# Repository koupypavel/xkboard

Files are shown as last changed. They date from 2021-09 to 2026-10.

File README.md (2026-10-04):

# XKboard

XKboard is a modular embedded development and teaching platform made of two independent PCBs:

| Board | Main device | On-board debug/programming | Docs |
|---|---|---|---|
| **XKboard MCU** | NXP LPC4327 (ARM Cortex-M4F + Cortex-M0 co-processor) | LPC11U35 CMSIS-DAP probe (see [known issues](#known-issues)), 10-pin JTAG/SWD header | [xkboard_mcu/README.md](xkboard_mcu/README.md) |
| **XKboard FPGA** | Lattice MachXO3D LCMXO3D-9400HC-5SG72C | FTDI FT2232HL USB-JTAG bridge, 10-pin JTAG header | [xkboard_fpga/README.md](xkboard_fpga/README.md) |

Each board works standalone and can be programmed and debugged on its own. Both boards expose
**Arduino-compatible headers** (3.3 V logic only), so standard Arduino shields can be attached.
The boards can also be stacked through the dedicated **`FPGA_CONF`** header, which carries
I2C and SPI between the two. With the boards stacked, the MCU can configure the FPGA (program
its internal flash through the MachXO3D sysCONFIG interface) and exchange data with the logic
running in it.

The project is inspired by the FITkit / Minerva boards used for teaching at FIT BUT. Unlike Minerva,
it splits the MCU and the FPGA onto separate, simpler boards. It was developed as the author's
master's thesis (see [Background](#background)).

## Repository layout

```
.
├── doc.pdf                    Master's thesis (Czech) – full technical report
├── docs/
│   ├── examples.md            Demonstration examples (MCU + FPGA + interconnect)
│   └── hardware-design.md     PCB design, manufacturing, assembly and bring-up notes
├── xkboard_mcu/               MCU board
│   ├── case/                  3D-printable enclosure (top.stl, bottom.stl)
│   ├── dps/                   Altium Designer project (schematics, PCB, libraries, outputs zip)
│   ├── firmware/              MCUXpresso examples, board library, OpenOCD/FT_PROG/FlashMagic configs
│   └── schema.pdf             Schematics
└── xkboard_fpga/              FPGA board
    ├── case/                  3D-printable enclosure (top.stl, bottom.stl)
    ├── dps/                   Altium Designer project (schematics, PCB, outputs zip)
    ├── firmware/              Lattice Diamond VHDL examples, FT_PROG template
    └── schema.pdf             Schematics
```

`dps` is the Czech abbreviation for PCB (*deska plošných spojů*).

## Getting started

1. **Pick a board.** Read the hardware overview and pinout in
   [xkboard_mcu/README.md](xkboard_mcu/README.md) or [xkboard_fpga/README.md](xkboard_fpga/README.md).
2. **Install the toolchain.**
   - MCU: [MCUXpresso IDE](https://www.nxp.com/mcuxpresso/ide) (GNU Arm Embedded toolchain included) and
     [OpenOCD](https://openocd.org/).
   - FPGA: [Lattice Diamond](https://www.latticesemi.com/latticediamond) (includes LSE, ModelSim Lattice
     Edition and the Reveal logic analyzer) and FTDI [FT_PROG](https://ftdichip.com/utilities/).
3. **Run the blink example** for your board. See [docs/examples.md](docs/examples.md#1-led-and-button-blink).
4. **Connect the boards.** Use the `FPGA_CONF` header for the I2C configuration and servo-control
   examples.

## Board interconnect

The `FPGA_CONF` header is in the same place on both boards. The FPGA board has pin headers on its
bottom side that plug into the female header on the MCU board.

| Signal | Function |
|---|---|
| `SCL`, `SDA` | I2C. Used for FPGA configuration (MachXO3D configuration port at 7-bit address `0x40`) and for user communication through the EFB I2C controllers |
| `CCLK`, `MOSI`, `MISO`, `SN` | SPI. Can be used for slave-SPI configuration of the FPGA or for user communication |
| `DONE`, `INITN` | FPGA configuration status pins |
| `GND` | Common ground |

> **Note:** On the MCU side the `FPGA_CONF` pins are not pre-assigned to these functions after reset. The
> firmware must configure the pin multiplexing (SCU) before any transfer.

Any free GPIOs (`MCU_IO` / `FPGA_IO` headers, Arduino headers) can also be used for custom protocols. The
servo-control example uses a simple 3-wire clock/data/strobe protocol.

## Known issues

- **MCU on-board debug probe:** the LPC11U35 CMSIS-DAP probe (DAPLink/SWDAP-based) is not usable in this
  revision. The JTAG TDI/TDO lines are not routed, and the LPC4327 comes up in JTAG mode by default.
  Use an external FT2232H-based JTAG adapter on the `SWD/JTAG` header instead (see
  [xkboard_mcu/README.md](xkboard_mcu/README.md#debugging)). A future revision should replace the probe,
  for example with an NXP MCU-Link-style design with full JTAG support.
- **MCU boot-mode pins** and the **FPGA reset circuit** needed rework during bring-up. See
  [docs/hardware-design.md](docs/hardware-design.md#bring-up-notes).
- The external SPI flash on the FPGA board is populated, but it is not used as a configuration source.
- Programming the FPGA internal flash over I2C from the MCU is only partially implemented. Erase, status
  and ID readout work, but there is no storage interface large enough to hold a bitstream.

## Background

This work was the basis of the master's thesis *Modular teaching platform for embedded systems and digital
circuits* (*Modulární výuková platforma pro oblast vestavěných systémů a číslicových obvodů*),
Pavel Koupý, Brno University of Technology, Faculty of Information Technology, 2021. The full report (in Czech)
is [doc.pdf](doc.pdf). The READMEs in this repository are an English technical adaptation of its practical parts.

**Keywords:** development board, ARM Cortex-M, FPGA, Arduino compatible, CMSIS-DAP on-board debug interface.

## License

See [LICENSE](LICENSE).

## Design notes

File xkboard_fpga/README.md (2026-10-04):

# XKboard FPGA

FPGA development board based on the Lattice **MachXO3D** family. It has an on-board USB-JTAG bridge, an
Arduino-compatible header, and a header for stacking with the [XKboard MCU](../xkboard_mcu/README.md) board.

- Schematics: [schema.pdf](schema.pdf)
- Altium Designer project: [dps/](dps/) (`fitkit4_fpga.PrjPcb`; fabrication outputs in `xkboard_fpga.zip`)
- Enclosure: [case/](case/) (`top.stl`, `bottom.stl`)
- VHDL examples and FT_PROG template: [firmware/](firmware/README.md)

The board design draws on FITkit 3 (Minerva), Spartan Edge Accelerator and Arty S7. Lattice was chosen over
Xilinx because the MachXO3D can be configured over open interfaces (I2C, SPI, JTAG) without a vendor-specific
programming cable.

## Hardware

### FPGA

| Parameter | Value |
|---|---|
| Device | Lattice LCMXO3D-9400HC-5SG72C |
| Logic | 9400 LUT4s, EBR block RAM, distributed RAM |
| Package | QFN72 with exposed pad, 58 user I/O |
| Supply | 2.5–3.3 V (core and I/O banks; 3.3 V on this board) |
| Non-volatile memory | Internal configuration flash (CFG0/CFG1) and user flash (UFM) |
| Hard IP | EFB: 2× I2C, SPI, timer/counter, UFM access, sysCONFIG via Wishbone. ESB: AES-128/256, SHA-256/HMAC, ECC, TRNG. sysCLOCK PLL |
| Clock | 12 MHz oscillator on pin 69 |

#### Architecture notes (MachXO3D)

- **PFU** (Programmable Functional Unit): 4 slices, each with 2 LUT4s and 2 registers. Slice modes are Logic (LUT4/LUT5),
  Ripple (2-bit add/sub, counters, comparators, multipliers with fast carry FCI/FCO), RAM (16×4 distributed
  single-port RAM) and ROM.
- **sysIO** buffers support LVTTL, LVCMOS33/25/18/15/12, I3C, LVDS and MIPI, depending on the bank VCCIO.
- **Clocking:** 8 primary clock inputs (`PCLK[T/C][bank]_[0..2]`). They can be used as general I/O when not
  needed as clock inputs.
- **EFB / ESB** blocks are accessed from user logic over a **Wishbone** bus. User logic must implement a
  Wishbone master: either a custom state machine, or a soft-core such as Mico8/Mico32. Lattice does not officially support
  those cores on MachXO3D (Mico8 supports MachXO3L).

**Internal flash map:** `CFG0` and `CFG1` hold the primary and secondary bitstreams. They are followed by
the user flash sectors `UFM0`–`UFM3`. A bitstream larger than a CFG sector may extend into the UFM sector
directly after it. The **Feature Row** is erased and programmed separately. It enables or disables the
configuration ports (I2C, SPI, JTAG) and the dedicated pins `PROGRAMN`, `INITN` and `DONE`.

**Configuration ports:** IEEE 1149.1 JTAG, self-download (from internal flash), master/slave SPI, dual boot,
I2C and Wishbone. All use the **sysCONFIG** command set. The device switches between **User**, **Offline**
and **Transparent** configuration modes. Offline mode must be entered before reprogramming, so that the
running logic is disabled while the flash or SRAM is rewritten.

### Debug and configuration

- **FTDI FT2232HL** USB 2.0 high-speed bridge. Channel A runs in MPSSE mode as a JTAG adapter for Lattice
  Diamond Programmer and the Reveal analyzer. Channel B is free (UART/FIFO/MPSSE). Program the EEPROM once with
  **FT_PROG** using [firmware/ft_prog/ftdi.xml](firmware/ft_prog/ftdi.xml) so that Diamond detects the
  cable.
- **`JTAG` header (10-pin)** for an external JTAG cable:

| Pin | Signal | Pin | Signal |
|---|---|---|---|
| 1 | 3.3 V | 2 | TMS |
| 3 | GND | 4 | TCK |
| 5 | GND | 6 | TDO |
| 7 | GND | 8 | TDI |
| 9 | GND | 10 | TRST |

JTAG header

- **`FPGA_CONF`** header (bottom side). The XKboard MCU can configure the FPGA over I2C or SPI through it.
  See the [root README](../README.md#board-interconnect).

### Power

- 5 V from micro-USB → **NCP1117DT33T5G** LDO, 3.3 V / 1 A, distributed on an inner plane.
- **The `VCC_CORE` and `VCC_0` jumpers must be closed** to power the FPGA core and bank 0.

### Peripherals

- **S25FL128S** 128 Mbit SPI flash. It is intended for configuration images or user data, for example shared with the MCU.
  It is populated, but it is not used as a configuration source in the current designs.
- 3 user LEDs and 2 user buttons:

| Component | FPGA pin |
|---|---|
| LED D1 | 28 |
| LED D2 | 30 |
| LED D3 | 31 |
| Button S1 | 26 |
| Button S2 | 27 |
| 12 MHz clock | 69 |

### Pinout

**Arduino headers and `FPGA_CONF`**. **3.3 V logic only.** The FPGA has no ADC, so the Arduino analog pins are
plain digital I/O.

Arduino-compatible headers and FPGA_CONF

**`FPGA_IO` header**. Spare FPGA I/O (pins named by the MachXO3D pad name).

| Pin | Signal | Pin | Signal |
|---|---|---|---|
| 1 | 3.3 V | 2 | 3.3 V |
| 3 | 3.3 V | 4 | PL29B |
| 5 | PB7B | 6 | PL30A |
| 7 | PL25A | 8 | PL30B |
| 9 | GND | 10 | GND |
| 11 | PL25B | 12 | PL30C |
| 13 | PL27A | 14 | PR5A |
| 15 | GND | 16 | GND |
| 17 | PL27B | 18 | PT23A |
| 19 | PL29A | 20 | PT23B |

FPGA_IO header

## Software

### Toolchain

**Lattice Diamond** (3.12 was used) covers the whole flow: HDL entry, IP configuration (IPexpress),
synthesis (LSE), place and route, timing analysis, bitstream generation, programming and on-chip debugging.
Unlike the MCU flow, a practical IDE-free (Makefile-only) flow is not available.

Lattice Diamond

Useful views:

- **Spreadsheet View**: pin assignment and I/O settings (I/O standard, pull mode, slew rate). *Global
  Preferences* holds sysCONFIG options such as `I2C_PORT` and `SLAVE_SPI_PORT`.
- **Netlist View / Netlist Analyzer**: the synthesized design as a schematic of primitives.
- **Floorplan / Physical View**: placement relative to the package. Supports cross-probing between views.
- **Timing Analysis View**.
- **IPexpress**: configurable IP blocks (EFB, FIFOs, adders, PLL, power controller, …).

### Creating a project

1. **File → New → Project** (New Project wizard).
2. Select the device: MachXO3D, **LCMXO3D-9400HC**, speed grade **5**, package **QFN72** (`-5SG72C`).
3. Add the VHDL/Verilog sources. All other files are optional: the `.lpf` constraints file, synthesis
   constraints, Reveal `.rvl` files and IP `.ipx` files.
4. Assign pins in Spreadsheet View, or copy the `LOCATE COMP` lines from an example `.lpf`.

### Simulation

The simulation wizard creates a **ModelSim Lattice Edition** project from the design. ModelSim is installed with Diamond.

### Synthesis and implementation

The **Process** pane runs the flow in order:

1. **Synthesize Design**: LSE (Lattice Synthesis Engine) infers ROM/RAM, FSMs and arithmetic and writes an NGD
   netlist. Supported languages: VHDL-87/93 (`numeric_bit`, `numeric_std`, `std_logic_1164`,
   `std_logic_arith`, `std_logic_signed/unsigned`, `math_real`) and Verilog-95/2001.
2. **Map Design** and **Place & Route Design**, using the constraints in the `.lpf`.
3. **Export Files**: JEDEC (`.jed`) or bitstream (`.bit`, binary or hex).

### Programming

Open **Tools → Programmer**. Diamond detects the FT2232HL as a USB cable. Select the device (family, part, package)
and an access mode:

| Target | Operation | Persistence |
|---|---|---|
| SRAM | *SRAM Fast Configuration* | Lost at power-off. Use for quick tests and debugging |
| Internal flash (CFG0/CFG1) | *FLASH Erase, Program, Verify* | Non-volatile. Loaded into SRAM at power-up (self-download mode) |
| External SPI flash | — | Populated, not implemented |

The FPGA can also be configured from the XKboard MCU over I2C. See the
[I2C configuration example](../docs/examples.md#2-fpga-configuration-over-i2c).

### Debugging with Reveal

FPGA designs are debugged with an embedded logic analyzer rather than a software debugger:

1. **Reveal Inserter**: select the signals to sample, the trigger signals and the buffer depth. Diamond inserts the
   analyzer core and a JTAG hub into the design. Re-run the flow afterwards.
2. **Reveal Analyzer**: connects through the FT2232HL JTAG bridge, configures the trigger conditions, and
   shows the captured samples on a timeline. Captures can be exported as `.vcd`, for example for ModelSim.

> Simulate before running on hardware. A bad pin assignment or a short to external circuitry can damage
> the FPGA despite its protection features.

## Firmware examples

See [firmware/README.md](firmware/README.md) and [docs/examples.md](../docs/examples.md).

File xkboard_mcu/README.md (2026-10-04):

# XKboard MCU

ARM Cortex-M development board based on the NXP **LPC4327**. It has an Arduino-compatible header,
a QSPI flash and a header for stacking with the [XKboard FPGA](../xkboard_fpga/README.md) board.

- Schematics: [schema.pdf](schema.pdf)
- Altium Designer project: [dps/](dps/) (`fitkit4.PrjPcb`; fabrication outputs in `xkboard_mcu.zip`)
- Enclosure: [case/](case/) (`top.stl`, `bottom.stl`)
- Firmware, board library and tool configs: [firmware/](firmware/README.md)

MCU board running the blink example

## Hardware

### Microcontroller

| Parameter | Value |
|---|---|
| Device | NXP LPC4327JBD144 (LQFP144) |
| Cores | ARM Cortex-M4F (with FPU) + ARM Cortex-M0 co-processor, up to 204 MHz |
| Memory | On-chip flash, 136 kB SRAM |
| Clock | 12 MHz external crystal |
| Interfaces | I2C, I2S, SPI/SSP, UART/USART, USB, SPIFI, EMC (external memory controller), ADC |
| Debug | JTAG / SWD, both cores |

The board was designed for the LPC4337. The LPC4327 was fitted because of component shortages. It is
practically identical, but has a smaller on-chip flash.

The two cores communicate through shared RAM and inter-core interrupts. The M4 is the master and sets up the M0. Two queues
in shared memory are used: `CMD_BUFFER` (M4 → M0) and `MSG_BUFFER` (M0 → M4). Each queue is
described by a start address, an end address, a read pointer and a write pointer. The queue mechanism has no overflow protection and no
error reporting. The sender must check for free space itself.

The EMC can also be used as a parallel interface to the FPGA (up to 16 bits per clock cycle), but this is
not implemented on the current interconnect.

### Debug and programming

- **On-board probe:** an LPC11U35 that runs CMSIS-DAP firmware (based on the open-source DAPLink/SWDAP design).
  It has its own micro-USB connector. **It does not work in this revision**, see [Debugging](#debugging).
- **`SWD/JTAG` header (10-pin):** connects an external probe. The board can also be powered from this header (3.3 V).

| Pin | Signal | Pin | Signal |
|---|---|---|---|
| 1 | 3.3 V | 2 | TMS |
| 3 | GND | 4 | TCK |
| 5 | GND | 6 | TDO |
| 7 | GND | 8 | TDI |
| 9 | GND | 10 | TRST |

SWD/JTAG header

These pins default to the debug functions after reset. The MCU can therefore always be reached over JTAG,
even when the application has reconfigured all other interfaces.

### Power

- Two micro-USB connectors: **debug** (probe) and **MCU I/O** (LPC4327 USB0).
- **TPS77733DR** LDO, 3.3 V / 750 mA. Supplies the LPC4327 and the 3.3 V inner plane.
- **TC1017** LDO, 3.3 V / 150 mA. Supplies the LPC11U35 probe.
- The debug USB port supplies both regulators. The MCU I/O USB port supplies only the LPC4327 side, so the
  probe stays off.
- The Arduino `5V` pin is connected directly to USB VBUS. Arduino `VIN` feeds the 3.3 V regulator through a removable
  jumper. The two USB supplies are also separated by a jumper.

### Peripherals

- **S25FL128S** 128 Mbit QSPI NOR flash on the SPIFI interface (P3_3–P3_8), up to 52 MB/s. The MCU can
  boot from it, and it can store FPGA configuration images.
- 3 user LEDs and 2 user buttons:

| Component | Pin | GPIO | Board API |
|---|---|---|---|
| LED | P6_7 | GPIO5[15] | `Board_LED_*(0)` |
| LED | P6_9 | GPIO3[5] | `Board_LED_*(1)` |
| LED | P6_11 | GPIO3[7] | `Board_LED_*(2)` |
| Button SW3 | P6_3 | GPIO3[2] | `BUTTONS_BUTTON_1` |
| Button SW4 | P6_6 | GPIO0[5] | `BUTTONS_BUTTON_2` |

### Pinout

**Arduino headers and `FPGA_CONF`**. All I/O is **3.3 V only**. Applying 5 V logic can damage the LPC4327.
The Arduino analog pins A0–A5 are labeled `ADC0`–`ADC5`. The servo example reads A0/A1 as ADC0 channels 0/1.

Arduino-compatible headers and FPGA_CONF

The `FPGA_CONF` labels (`SCL`, `SDA`, `CCLK`, `MOSI`, `MISO`, `SN`, `DONE`, `INITN`) describe the intended
use. The pins are **not** pre-configured for these functions, so set the pin multiplexing in firmware
before use.

**`MCU_IO` header**. Spare MCU pins. Pins 3/4 (P2_0/P2_1) are USART0, which the UART ISP bootloader uses.

| Pin | Signal | Pin | Signal |
|---|---|---|---|
| 1 | P9_6 | 2 | P9_5 |
| 3 | P2_0 (U0_TXD) | 4 | P2_1 (U0_RXD) |
| 5 | P2_2 | 6 | P2_3 |
| 7 | P2_4 | 8 | P2_5 |
| 9 | P2_6 | 10 | P1_0 |
| 11 | P1_3 | 12 | P1_4 |
| 13 | P1_5 | 14 | P1_6 |
| 15 | P1_7 | 16 | P1_8 |
| 17 | P1_9 | 18 | P1_10 |
| 19 | P1_11 | 20 | P1_12 |

MCU_IO header

### Boot modes

The boot source is selected by the levels of P2_9, P2_8, P1_2 and P1_1 at reset. If all four pins are low,
the MCU starts the USART0 ISP bootloader.

| Boot mode | P2_9 | P2_8 | P1_2 | P1_1 | Notes |
|---|---|---|---|---|---|
| USART0 ISP | L | L | L | L | UART ISP on P2_0 / P2_1 (`MCU_IO` pins 3/4) |
| SPIFI | L | L | L | H | On-board QSPI flash |
| EMC 8-bit | L | L | H | L | Parallel external memory (16-bit also supported) |
| USB0 ISP | L | H | L | H | USB connector next to R31; requires the 12 MHz oscillator |
| SPI (SSP0) | L | H | H | H | P3_3 SCK, P3_6 SSEL, P3_7 MISO, P3_8 MOSI |
| USART3 ISP | H | L | L | L | |

## Software

### Toolchain

- **MCUXpresso IDE** (NXP, Eclipse-based). It generates the Makefiles, linker scripts and startup code and builds with
  the **GNU Arm Embedded** toolchain (`arm-none-eabi-gcc`, binutils, GDB).
- **LPCOpen** for LPC43xx: the `lpc_chip_43xx` chip library. The examples are based on the LPCXpresso4337 package
  [firmware/examples/lpcopen_3_02_lpcxpresso4337.zip](firmware/examples/lpcopen_3_02_lpcxpresso4337.zip).
- **xkboard_mcu_4327**: the board support library for this board. It implements the generic LPCOpen
  `board_api.h` interface in `board.c` / `board.h` (clock setup, pin muxing, debug UART, LEDs, buttons, I2C,
  SSP, UART, GPIO interrupts).

MCUXpresso IDE

Library dependencies

The board library sets up the SCU pin multiplexing and the peripheral clocks, so applications do not write
these registers bit by bit. Main board API functions:

| Function | Purpose |
|---|---|
| `Board_SystemInit()` | Clock and pin-mux setup, called from `SystemInit()` before `main()` |
| `Board_Init()` | Debug UART (USART0), GPIO defaults, LEDs, buttons |
| `Board_LED_Set(n, state)`, `Board_LED_Toggle(n)`, `Board_LED_Test(n)` | User LEDs 0–2 |
| `Board_Buttons_Init()`, `Buttons_GetStatus()` | User buttons (`BUTTONS_BUTTON_1`, `BUTTONS_BUTTON_2`) |
| `Board_I2C_Init(id)`, `Board_SSP_Init(pSSP)`, `Board_UART_Init(pUART)` | Peripheral pin muxing |
| `DEBUGSTR()`, `DEBUGOUT()` | Debug output on USART0 |

### Creating a project

1. Import `lpc_chip_43xx` (from the LPCOpen zip) and
   [firmware/examples/10_xkboard_mcu_4327](firmware/examples/10_xkboard_mcu_4327) into the MCUXpresso workspace.
2. **File → New → Project → LPCOpen – C Project**, target LPC4337/LPC43xx (M4 core).
3. Select `lpc_chip_43xx` as the chip library and `xkboard_mcu_4327` as the board library. The IDE builds both as
   static libraries and links them into the application.
4. Build with **Project → Build**. The IDE runs `make` with `arm-none-eabi-gcc`.

### Flashing

- **External JTAG + OpenOCD/GDB** (recommended): see [Debugging](#debugging). Use the GDB `load` command or OpenOCD
  `flash write_image`.
- **UART ISP**: pull all boot pins low, connect a USB-UART adapter to `MCU_IO` pins 3/4 (P2_0/P2_1) and program
  with **FlashMagic**. A project template is in
  [firmware/flashmagic_prj/lpc4327.fmx](firmware/flashmagic_prj/lpc4327.fmx).
- **USB ISP**: select the USB0 boot mode (requires the 12 MHz oscillator).
- **Drag-and-drop**: CMSIS-DAP/DAPLink mass-storage programming. This needs a working on-board probe, which this
  revision does not have.

### Debugging

The on-board LPC11U35 probe cannot debug the LPC4327 in this revision:

- **DAPLink** firmware supports SWD only. The LPC4327 starts in JTAG mode and must first be switched to SWD over JTAG, so a
  pure SWD probe cannot connect.
- **IBDAP** (JTAG-capable CMSIS-DAP) needs TDI/TDO from the LPC11U35 (pins 18 and 27), which are not routed. A
  hand-wired attempt with 33 Ω series resistors did not work.
- **Black Magic Probe** firmware can run on a PC (hosted build) with an FT2232H MPSSE adapter. It works, but it is
  redundant because OpenOCD supports the FT2232H directly.

**Working setup: external FT2232H(L) JTAG adapter.** A simple FT2232HL breakout board (FT2232HL, configuration
EEPROM, crystal) is connected to the `SWD/JTAG` header. It can also power the board with 3.3 V. The adapter
needs no firmware. Only its EEPROM has to be programmed once with **FT_PROG** using the template
[firmware/ft_prog/FTDIJTAG.xml](firmware/ft_prog/FTDIJTAG.xml).

```bash
openocd -f xkboard_mcu/firmware/openocd_config/dp_busblaster.cfg -f xkboard_mcu/firmware/openocd_config/lpc4327.cfg
```

| File | Content |
|---|---|
| `dp_busblaster.cfg` | FT2232H adapter (Bus Blaster-compatible wiring), channel A, JTAG transport |
| `openocd-usb.cfg` | Alternative FTDI layout matched by the device description `FTDIJTAG` (as programmed by the FT_PROG template) |
| `lpc4327.cfg` | LPC4327 target, Cortex-M4 TAP, 100 kHz adapter clock, 128 kB work area at `0x10000000` |

To debug the Cortex-M0 core as well, use the stock OpenOCD `target/lpc4350.cfg`. It declares both TAPs (M4 and M0).

OpenOCD starts a GDB server (port 3333 by default) and a Telnet console (port 4444). Connect from MCUXpresso
(a GDB hardware-debugging configuration) or from the command line:

```bash
arm-none-eabi-gdb Debug/10_1_blink.axf -ex "target extended-remote :3333" -ex "monitor reset halt" -ex load
```

**pyOCD** is a Python alternative for CMSIS-DAP probes. LPC4327 support needs the Keil MDK5 device pack. This
project does not use it.

## Firmware examples

See [firmware/README.md](firmware/README.md) and [docs/examples.md](../docs/examples.md).

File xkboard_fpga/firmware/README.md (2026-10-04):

# XKboard FPGA – firmware

| Directory | Content |
|---|---|
| [examples/](examples/) | Lattice Diamond VHDL projects (open the `.ldf` file) |
| [ft_prog/](ft_prog/) | `ftdi.xml`: FT_PROG EEPROM template for the on-board FT2232HL, so that Diamond detects it as a programming cable |

## Examples

The numbering follows chapter 10 of the thesis. Full descriptions are in [docs/examples.md](../../docs/examples.md).

| Project | Description | Key files |
|---|---|---|
| `10_1_blink` | LEDs D1–D3 blink at 1/5/10/20 Hz, selected by S1/S2. Includes a Reveal analyzer setup and a ModelSim project | `top.vhd`, `Blinky.lpf`, `rev_test.rvl`, `sim_blinky/` |
| `10_2_i2c_config` | EFB with I2C enabled, so the configuration port stays reachable from the MCU in user mode | `efb_i2c_conf.vhd` / `.ipx`, `i2c_config.lpf` |
| `10_3_multifunc_shield` | Drives the multi-function shield 7-segment display ("AHOJ") through 74HC595 shift registers | `top.vhd`, `multi_shield.lpf` |
| `10_4_servo_control` | Receives 8-bit servo commands from the MCU and generates three 50 Hz PWM outputs | `top.vhd`, `servo_control.lpf` |

Target device in all projects: **LCMXO3D-9400HC-5SG72C**, 12 MHz clock on pin 69.

See [../README.md](../README.md#software) for the Diamond flow, programming and Reveal debugging.

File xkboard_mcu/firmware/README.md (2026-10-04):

# XKboard MCU – firmware

| Directory | Content |
|---|---|
| [examples/](examples/README.md) | MCUXpresso example projects and the `xkboard_mcu_4327` board library |
| [ft_prog/](ft_prog/) | `FTDIJTAG.xml`: FT_PROG EEPROM template for the external FT2232H JTAG adapter |
| [openocd_config/](openocd_config/) | OpenOCD adapter and target configurations for debugging the LPC4327 |
| [flashmagic_prj/](flashmagic_prj/) | `lpc4327.fmx`: FlashMagic project for programming the LPC4327 over UART ISP |

See [../README.md](../README.md#software) for the toolchain, flashing and debugging instructions.

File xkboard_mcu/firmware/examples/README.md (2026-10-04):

# XKboard MCU – examples

MCUXpresso IDE projects for the LPC4327 and the board support library. The numbering follows chapter 10 of the
thesis. All examples are described in [docs/examples.md](../../../docs/examples.md).

| Project | Description |
|---|---|
| `10_1_blink` | LED blink, buttons change the rate. The first test of a new board |
| `10_2_i2c_config` | I2C master talking to the MachXO3D configuration port (sysCONFIG commands in `machxo.c`) |
| `10_3_multifunction_shield` | 7-segment display, LEDs and buttons on the Arduino multi-function shield |
| `10_4_servo_control` | Joystick read with the ADC, servo commands sent to the FPGA board |
| `10_xkboard_mcu_4327` | Board support library (`board.c`, `board.h`, `board_api.h`, `board_sysinit.c`) |
| `lpcopen_3_02_lpcxpresso4337.zip` | NXP LPCOpen v3.02 package for LPCXpresso4337 (provides `lpc_chip_43xx` and vendor examples) |

## Importing into MCUXpresso

1. **File → Import → General → Existing Projects into Workspace**, then select this directory.
2. Import `lpc_chip_43xx` from `lpcopen_3_02_lpcxpresso4337.zip` (**Import project(s) from file system** → archive).
3. Build `lpc_chip_43xx` and `10_xkboard_mcu_4327`, then the example project.

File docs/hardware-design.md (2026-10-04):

# Hardware design, manufacturing and bring-up

This document covers how the two boards were designed, manufactured, assembled and brought up. For the
board-level descriptions, see [xkboard_mcu/README.md](../xkboard_mcu/README.md) and
[xkboard_fpga/README.md](../xkboard_fpga/README.md).

## Design concept

- **Two standalone boards** instead of one combined MCU+FPGA board, as in FITkit/Minerva. Each board is simpler
  and cheaper, and can be used alone. Stacked through `FPGA_CONF`, they form a more capable system.
- **On-board programming/debug adapters**, so that no vendor probe is needed: a CMSIS-DAP probe on the MCU board
  and an FT2232HL USB-JTAG bridge on the FPGA board. Standard 10-pin JTAG headers are kept as a fallback.
- **Arduino-compatible headers** on both boards give access to the existing shield ecosystem
  (3.3 V logic only).
- The **FPGA board** handles high-bandwidth peripherals and parallel hardware acceleration. The **MCU board**
  provides ready-made peripherals (USB, ADC, UART, …) that would otherwise have to be built in the FPGA.

## Schematic capture (Altium Designer)

Both projects use a **hierarchical** schematic. A top-level sheet shows every sub-sheet as a block and connects
them through ports, harnesses and buses.

| MCU board (`xkboard_mcu/dps`) | FPGA board (`xkboard_fpga/dps`) |
|---|---|
| `arm_board.SchDoc` (top) | `fpga_board.SchDoc` (top) |
| `mcu_core.SchDoc`: LPC4327, crystal, decoupling | `fpga_core.SchDoc`: MachXO3D, oscillator, decoupling |
| `mcu_debug.SchDoc`: LPC11U35 probe, JTAG/SWD header | `fpga_config.SchDoc`: FT2232HL, EEPROM, JTAG header |
| `mcu_headers.SchDoc`: Arduino, `FPGA_CONF`, `MCU_IO` | `fpga_headers.SchDoc`: Arduino, `FPGA_CONF`, `FPGA_IO` |
| `mcu_peripheral.SchDoc`, `mcu_io.SchDoc`: QSPI flash, LEDs, buttons, USB | `fpga_peripherals.SchDoc`: SPI flash, LEDs, buttons |
| `mcu_power.SchDoc`: LDOs, USB power | `fpga_power.SchDoc`: LDO, jumpers |

Connectivity uses wires, net labels, buses, signal harnesses (`*.Harness`), sheet ports and power ports.
Component symbols and footprints come from the Celestial Altium Library, SnapEDA and distributor models
(Mouser). Always check downloaded footprints against the datasheet of the part you actually buy, because
auto-generated models are sometimes wrong or out of date.

## PCB layout

| Parameter | Value |
|---|---|
| Stack-up | 4 layers, FR4, 1.6 mm |
| Inner layers | GND and 3.3 V planes, reached through power vias |
| Smallest passives | 0603 (hand-solderable) |
| IC packages | LQFP (LPC4327), QFN (MachXO3D, LPC11U35, FT2232HL), SOP |
| Fabrication | Gatema POOL prototype service, Gerber output |

Layout guidelines:

- Keep the **placement** close to the schematic arrangement. Use Altium cross-select and cross-probe to place parts
  group by group.
- **EMC:** minimise current-loop area and trace length, separate high- and low-frequency sections, do not
  use faster parts than needed, protect power and I/O lines against ESD and transients.
- **Grounding:** connect each ground pin to the GND plane by the shortest possible path (multi-point grounding, suitable for digital circuits).
- **Decoupling:** place local (decoupling) capacitors as close to each IC power pin as possible. Add bulk capacitors per
  power domain and bypass filtering at the power input.
- **Routing:** route the critical nets by hand first: clocks, USB pairs, QSPI and power. Use the
  autorouter only as an aid. Optimal routing is NP-hard, so autorouters use heuristics, and they handle DDR and
  analog nets poorly.

Fabrication outputs (Gerber, drill files, BOM) are generated with the `*.OutJob` files and archived in
`dps/xkboard_mcu.zip` and `dps/xkboard_fpga.zip`.

Unit reminder: 1 mil = 0.0254 mm, 1 mm ≈ 39.37 mil, 1 in = 25.4 mm.

## Assembly

Both boards are designed for hand assembly:

- 0603 passives and LQFP parts: soldering iron with a fine conical tip. Use a hoof or flat tip for drag-soldering LQFP
  pins.
- QFN parts with an exposed thermal pad: solder paste and hot air.
- Order: bottom side first (decoupling capacitors, flash). Then populate the top side **block by block, testing each block
  as it is fitted**.

The most common failure is misalignment of fine-pitch parts. The 144-pin LPC4327 is especially prone to shorts that
cannot be seen by eye. Use a multimeter for supply rails and shorts, and a logic analyzer or oscilloscope for
crystals and buses (JTAG, SPI). A Saleae logic analyzer was used during bring-up.

## Bring-up notes

### MCU board

1. Fit the **debug probe** (LPC11U35 + TC1017 LDO) first. When connected over micro-USB it should enumerate as a USB
   mass-storage device, which accepts a firmware binary.
2. Fit the **3.3 V supply** (TPS77733) and the **LPC4327**. Then try to connect over JTAG.
3. Fixes found during bring-up:
   - The **boot-mode pins** were wired incorrectly and had to be corrected (see the boot-mode table in the
     [MCU README](../xkboard_mcu/README.md#boot-modes)).
   - The **on-board probe** cannot be used: the LPC4327 starts in JTAG mode, and the probe's TDI/TDO lines are not routed.
     Use an external FT2232H JTAG adapter on the `SWD/JTAG` header.

### FPGA board

1. Fit the **FT2232HL** first. Over USB it should enumerate as an unknown device until the FTDI drivers are
   installed, then as a serial/JTAG device. Program its EEPROM with FT_PROG
   ([ftdi.xml](../xkboard_fpga/firmware/ft_prog/ftdi.xml)).
2. Close the **`VCC_CORE`** and **`VCC_0`** jumpers to power the FPGA.
3. Fix found during bring-up: the **reset circuit** held the FPGA in reset permanently and had to be reworked.

## Ideas for the next revision

- Replace the MCU-board debug probe with a design that has full JTAG support, for example based on NXP MCU-Link.
- Complete the FPGA bitstream path from the MCU (QSPI flash, SD card or USB as the source).
- Use the FPGA-board SPI flash as a configuration source.
- Add more examples and an online, install-free way to try them.

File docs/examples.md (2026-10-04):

# Demonstration examples

The examples are numbered as in chapter 10 of the thesis ([doc.pdf](../doc.pdf)). Each one has an MCU
implementation and/or an FPGA implementation:

| # | Example | MCU project | FPGA project | Boards connected |
|---|---|---|---|---|
| 1 | [LED and button blink](#1-led-and-button-blink) | `10_1_blink` | `10_1_blink` | no |
| 2 | [FPGA configuration over I2C](#2-fpga-configuration-over-i2c) | `10_2_i2c_config` | `10_2_i2c_config` | yes (`FPGA_CONF`) |
| 3 | [Arduino multi-function shield](#3-arduino-multi-function-shield) | `10_3_multifunction_shield` | `10_3_multifunc_shield` | no |
| 4 | [Servo arm control](#4-servo-arm-control) | `10_4_servo_control` | `10_4_servo_control` | yes (GPIO) |

MCU projects are in [xkboard_mcu/firmware/examples](../xkboard_mcu/firmware/examples/README.md) (MCUXpresso). FPGA
projects are in [xkboard_fpga/firmware/examples](../xkboard_fpga/firmware/README.md) (Lattice Diamond).

The MCU examples build on the NXP LPCOpen examples for LPC43xx and the `xkboard_mcu_4327` board library. The FPGA
I2C example is based on the Lattice EFB usage and I2C configuration application notes.

---

## 1. LED and button blink

The embedded "hello world". It checks the toolchain, the programming path and the basic I/O on each board.

### MCU

[`10_1_blink/src/blink.c`](../xkboard_mcu/firmware/examples/10_1_blink/src/blink.c)

- `Board_Init()` sets up the debug UART (USART0), the GPIO defaults, the LEDs and the buttons.
- The three LEDs (P6_7, P6_9, P6_11) are toggled with `Board_LED_Toggle(0..2)` in a busy-wait loop.
- SW3 / SW4 (P6_3, P6_6), read through `Buttons_GetStatus()`, shorten or lengthen the delay and so change the
  blink rate.
- Load and debug the build through OpenOCD + GDB (see [MCU debugging](../xkboard_mcu/README.md#debugging)).

MCU board blinking

### FPGA

[`10_1_blink/top.vhd`](../xkboard_fpga/firmware/examples/10_1_blink/top.vhd), constraints in `Blinky.lpf`

Four counters divide the 12 MHz clock (pin 69) into 1, 5, 10 and 20 Hz toggle signals. A multiplexer
controlled by buttons S1/S2 (pins 26/27) selects one of them and drives all three LEDs D1–D3 (pins 28/30/31):

| S1 | S2 | Blink rate |
|---|---|---|
| 0 | 0 | 1 Hz |
| 0 | 1 | 5 Hz |
| 1 | 0 | 10 Hz |
| 1 | 1 | 20 Hz |

FPGA blink circuit

The project includes a Reveal configuration (`rev_test.rvl`, `rev_analyzer.rva`) and a ModelSim project
(`sim_blinky/`). The capture below shows S1 being pressed and the 10 Hz source being selected:

Reveal capture

---

## 2. FPGA configuration over I2C

The MCU (I2C master) talks to the MachXO3D configuration port (I2C slave) through the `FPGA_CONF` header.
The FPGA side needs no user logic for this, because the sysCONFIG I2C port is part of the configuration
engine and also responds while the device is unconfigured.

### MCU

[`10_2_i2c_config`](../xkboard_mcu/firmware/examples/10_2_i2c_config): `src/i2c_config.c` (main loop),
`src/machxo.c` / `inc/machxo.h` (command set)

- I2C master is interrupt-driven (NVIC). Results are printed on USART0.
- `machxo.c` only builds the sysCONFIG command buffers. The main loop sends them over I2C to the 7-bit address
  `0x40` (`MACHXO_I2C_ADDR`).
- `printDetails()` reads the device ID, user code, Feature Row, feature bits and status register.

| Function | sysCONFIG operation |
|---|---|
| `cmd_readDeviceID`, `cmd_readUserCode`, `cmd_readStatus` | Identification and status |
| `cmd_readFeatureRow`, `cmd_readFeatureBits`, `cmd_readOTPFuses` | Feature Row / fuses |
| `cmd_enableConfigOffline`, `cmd_enableConfigTransparent` | Enter configuration mode |
| `cmd_erase(flags)` | Erase `MACHXO_ERASE_SRAM`, `_FEATURE_ROW`, `_CONFIG_FLASH`, `_UFM` |
| `cmd_isBusy` | Busy-flag polling |
| `cmd_resetConfigAddress`, `cmd_setConfigAddress`, `cmd_readFlash` | CFG flash access |
| `cmd_resetUFMAddress`, `cmd_setUFMAddress`, `cmd_readUFM`, `cmd_eraseUFM` | UFM access |
| `cmd_programDone`, `cmd_refresh`, `cmd_wakeup` | Finish programming and reload configuration |

Programming sequence:

```
cmd_enableConfigOffline()                       // stop user logic
cmd_erase(MACHXO_ERASE_CONFIG_FLASH | MACHXO_ERASE_UFM)
while (cmd_isBusy()) ;                          // poll until the erase finishes
<program pages from the bitstream source>
cmd_programDone()
cmd_refresh()                                   // load the new configuration
```

**Status:** identification, status readout and erase work. The page-programming step is not complete, because
the MCU has no interface yet for a bitstream-sized source such as SD card, USB mass storage or a UART upload. Possible sources:
the on-board QSPI flash, a hex stream over USART0 from a PC, or an SD card on an Arduino shield.

### FPGA

[`10_2_i2c_config`](../xkboard_fpga/firmware/examples/10_2_i2c_config): EFB instance `efb_i2c_conf` generated
with IPexpress

The FPGA accepts I2C configuration commands if either:

1. it has no valid configuration (CFG0/CFG1 erased or a new device), so it never enters user mode, or
2. the running design keeps the I2C configuration port enabled: `I2C_PORT` enabled in *Spreadsheet View →
   Global Preferences*. Diamond sets this automatically when an EFB with I2C is instantiated.

EFB settings:

- `wb_clk_i` must be at least **7.5× the I2C bus clock**. The default I2C clock is 100 kHz with 7-bit addressing.
- 7-bit address `aaaaabb`: the upper 5 bits are user-configurable (default `10000`). The lower 2 bits select the
  target: `00` configuration port (`0x40`), `01` primary user I2C, `10` secondary user I2C.
- Primary/secondary user I2C is reached from user logic through the EFB **Wishbone** slave. A Wishbone
  master (state machine or soft-core) is required. This is not needed for configuration.

---

## 3. Arduino multi-function shield

Uses a common "Multi-function Shield" on both boards, to show that the Arduino-compatible headers work.

Multi-function shield

Shield resources (Arduino pin numbering):

| Resource | Arduino pin |
|---|---|
| LEDs D1–D4 | D10–D13 |
| Buttons S1–S3 | A1–A3 |
| Potentiometer | A0 |
| Passive buzzer (needs a PWM tone) | D3 |
| 74HC595 latch / strobe (`st`) | D4 |
| 74HC595 clock | D7 |
| 74HC595 data | D8 |

**4-digit 7-segment display protocol.** The display is driven by two daisy-chained 74HC595 shift registers. Each
update sends **two bytes** MSB first, framed by the latch line:

1. Pull `st` low.
2. Shift out the **segment byte** (active low; for example `A`=`0x88`, `H`=`0x89`, `O`=`0xC0`, `J`=`0xE1`).
3. Shift out the **digit-select byte** (`0x01`, `0x02`, `0x04`, `0x08`).
4. Pull `st` high to latch.

Only one digit is lit at a time. Multiplexing fast enough makes all four digits appear lit at once. Both
implementations show the word `AHOJ`.

### MCU

[`10_3_multifunction_shield/src/main.c`](../xkboard_mcu/firmware/examples/10_3_multifunction_shield/src/main.c)

Uses plain GPIO bit-banging with an Arduino-style `shiftOut()`: for each bit, set the data line, then pulse the clock.
Clock is GPIO0[12], data GPIO2[13], latch GPIO0[2]. The potentiometer can be read with the ADC, which is not
possible on the FPGA board.

### FPGA

[`10_3_multifunc_shield/top.vhd`](../xkboard_fpga/firmware/examples/10_3_multifunc_shield/top.vhd), constraints in
`multi_shield.lpf` (clock pin 40, data 44, st 53; LEDs 16/36/20/19; buttons 63/59/58)

A state machine (`CURR_STATE`) sends the two bytes bit by bit. Each bit takes two states: data set with clock high,
then clock low to shift. A 2-bit counter drives multiplexers that select the letter and the digit address.

Shift protocol simulation

Shield on the FPGA board

---

## 4. Servo arm control

A 3-DOF 3D-printed arm with **MG995** servos, controlled from a **Joystick Shield V1.A**. Each board does the part it is
suited for: the MCU reads the joystick with its ADC, and the FPGA generates the three PWM signals with counters.

### Wiring

Servo example wiring

- The joystick shield is plugged into the MCU board (axes on A0/A1).
- The MCU and FPGA are connected by 3 wires: clock, data, strobe.
- The MG995 needs 5 V supply and 5 V PWM levels. Both boards use 3.3 V logic, so the servos use an
  **external 5 V supply** and a **level shifter**.

### Command format

One 8-bit command per servo, sent MSB first and framed by the strobe:

```
 7   6   5   4   3   2   1   0
[ servo addr ][   position    ]
  001 = A, 010 = B, 011 = C
```

The position is the 5 least-significant bits of the 8-bit ADC sample (the 3 MSBs are overwritten by the
address). This is coarse, but enough to show the function.

### MCU

[`10_4_servo_control/src/main.c`](../xkboard_mcu/firmware/examples/10_4_servo_control/src/main.c)

- ADC0 channels 0 and 1 (A0, A1) read by polling (`pool_ADC_val(channel)`), 8-bit result (~13 mV/LSB at 3.3 V).
- The joystick has two axes. The third servo is driven by a counter that the two on-board buttons increment or decrement.
- Clock GPIO0[15] (P1_20), data GPIO0[6] (P3_6), strobe GPIO5[10] (P3_7).

### FPGA

[`10_4_servo_control/top.vhd`](../xkboard_fpga/firmware/examples/10_4_servo_control/top.vhd), constraints in
`servo_control.lpf` (clock_i 20, data_i 35, st_i 36; servo_a/b/c 44/40/38)

- **Clock divider:** 12 MHz / 187 ≈ 64 kHz PWM tick.
- **PWM:** 50 Hz period = 20 ms = 1280 ticks. Pulse width ≈ 0.5–1.5 ms (≈ 32–96 ticks). Centre ≈ 1 ms = 64 ticks.
  Exact limits vary between servo clones.
- **Receiver:** a state machine (`idle`, `data_0`…`data_7`, `parse_cmd`) is started by the strobe, shifts in 8 bits
  on the clock, decodes the address, and updates that servo's compare value.

Servo arm driven by both boards

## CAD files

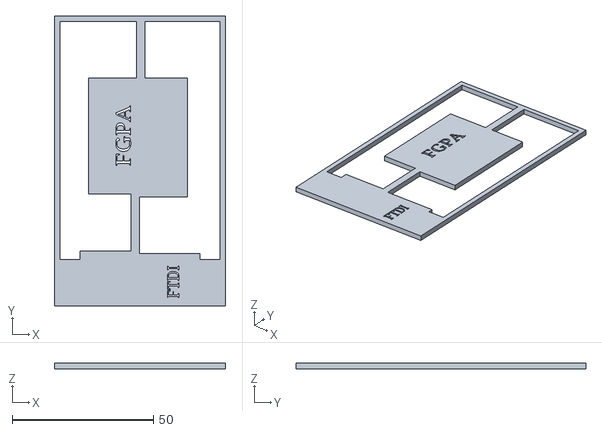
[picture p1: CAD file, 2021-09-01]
xkboard_fpga/case/top.stl
60.5 x 102.5 x 2.00

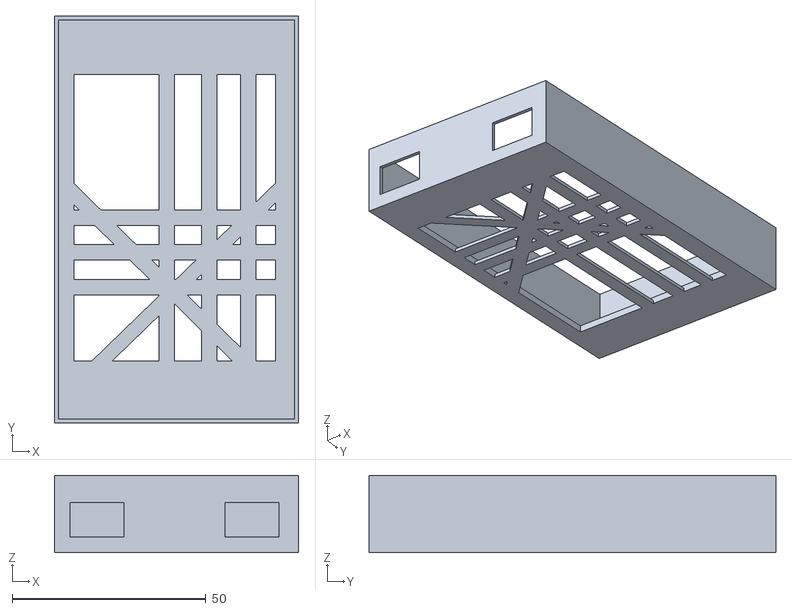
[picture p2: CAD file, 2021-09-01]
xkboard_mcu/case/bottom.stl
63.0 x 105.0 x 20.0

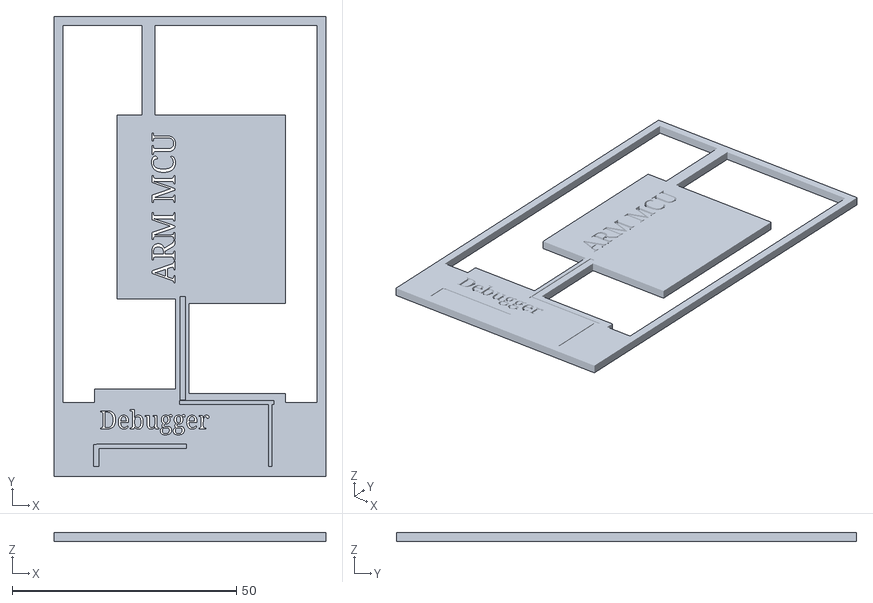
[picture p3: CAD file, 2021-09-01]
xkboard_mcu/case/top.stl
60.5 x 102.5 x 2.00

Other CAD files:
xkboard_fpga/case/bottom.stl

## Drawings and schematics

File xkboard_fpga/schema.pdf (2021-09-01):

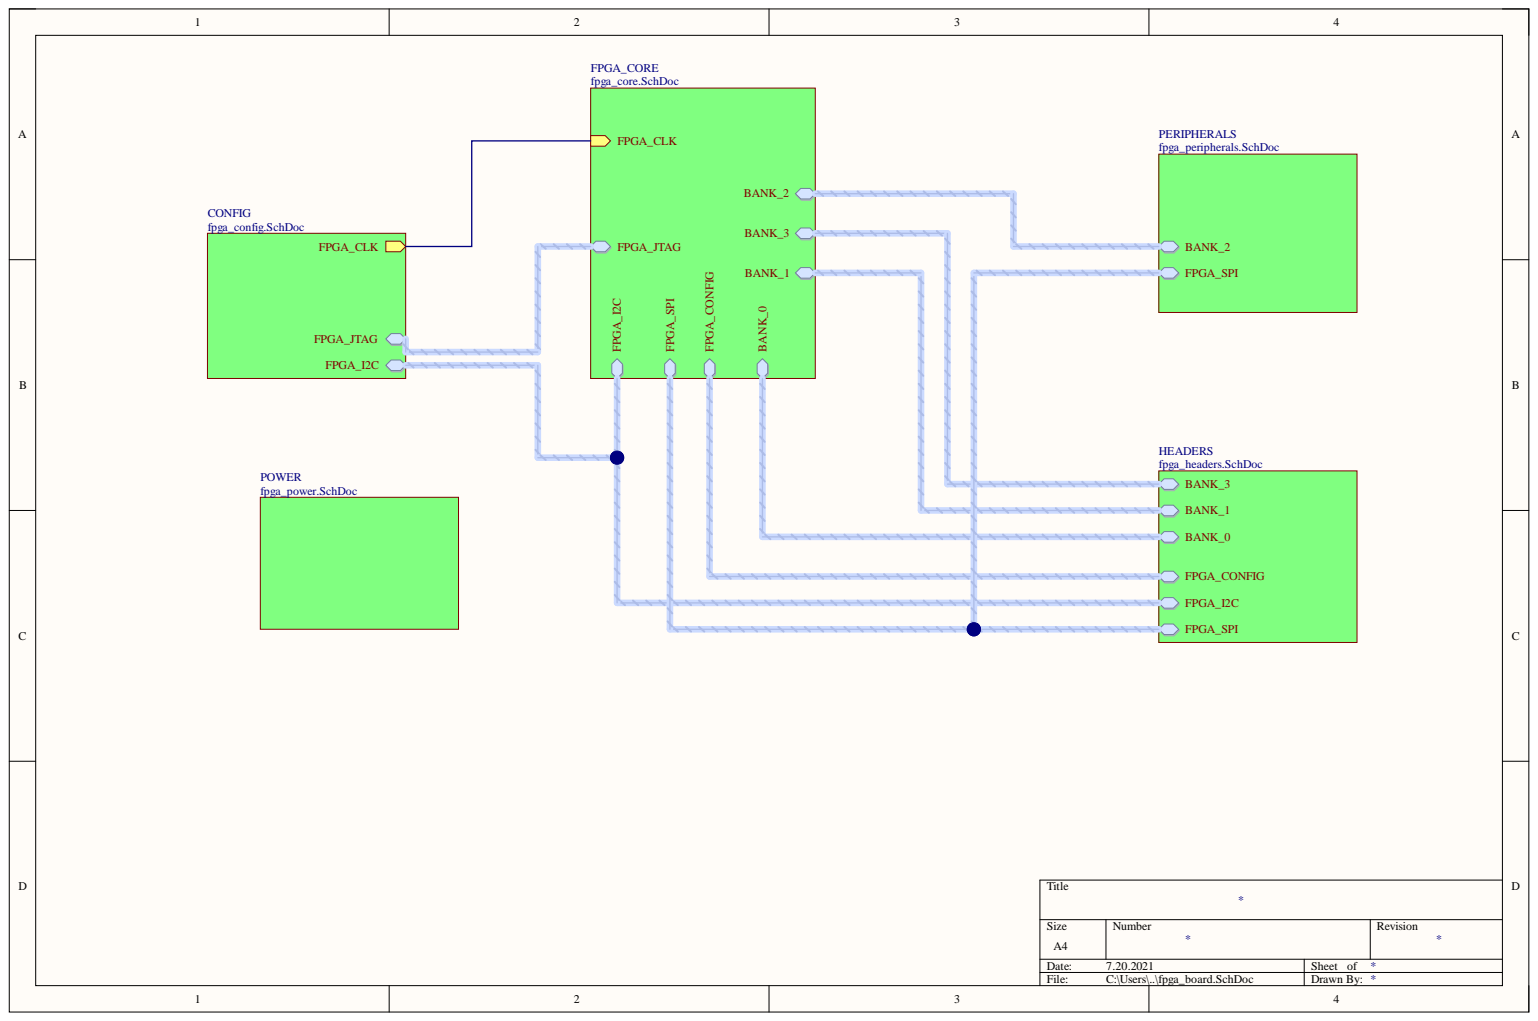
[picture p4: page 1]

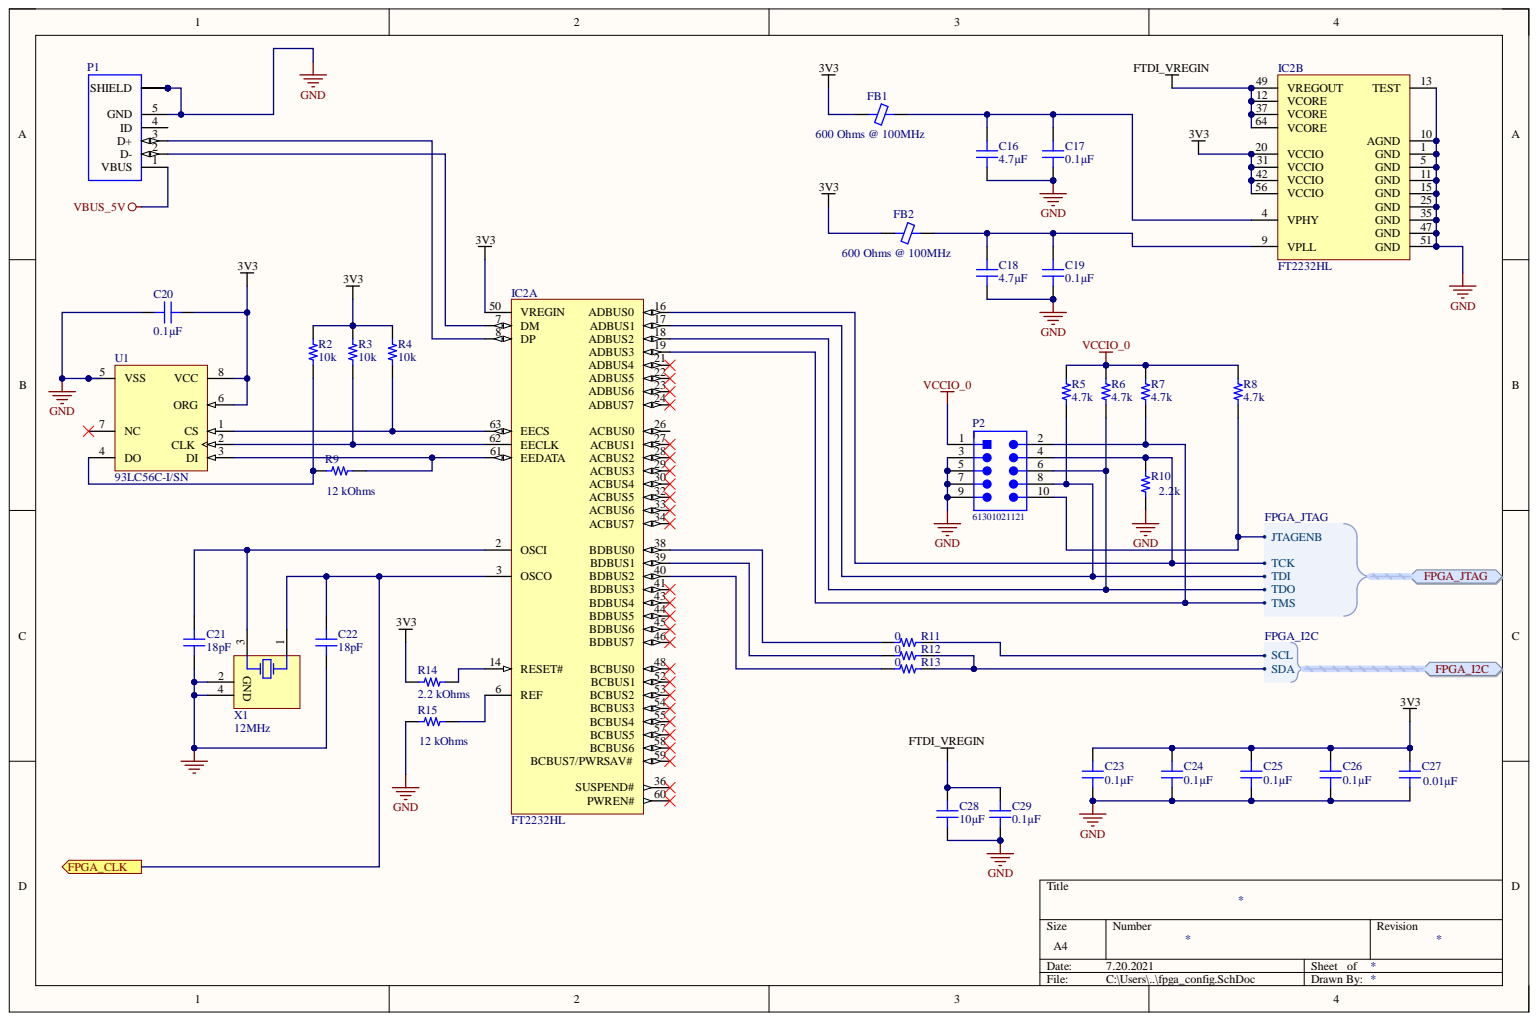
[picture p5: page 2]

VCCIO_0

VCCIO_0 | R8

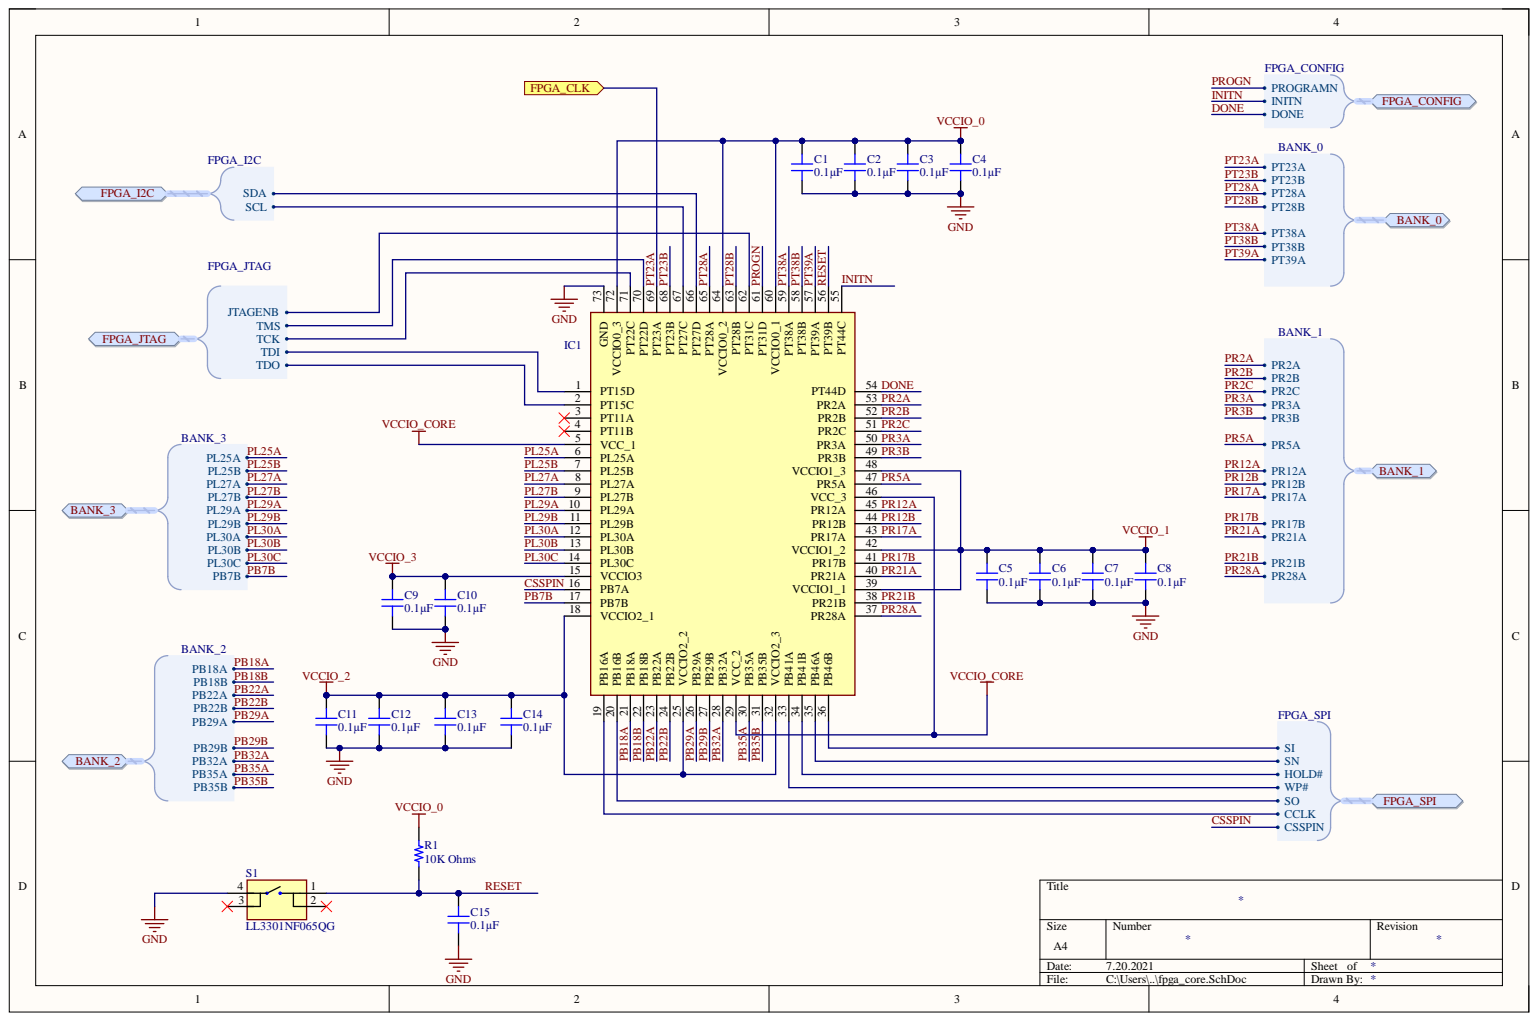
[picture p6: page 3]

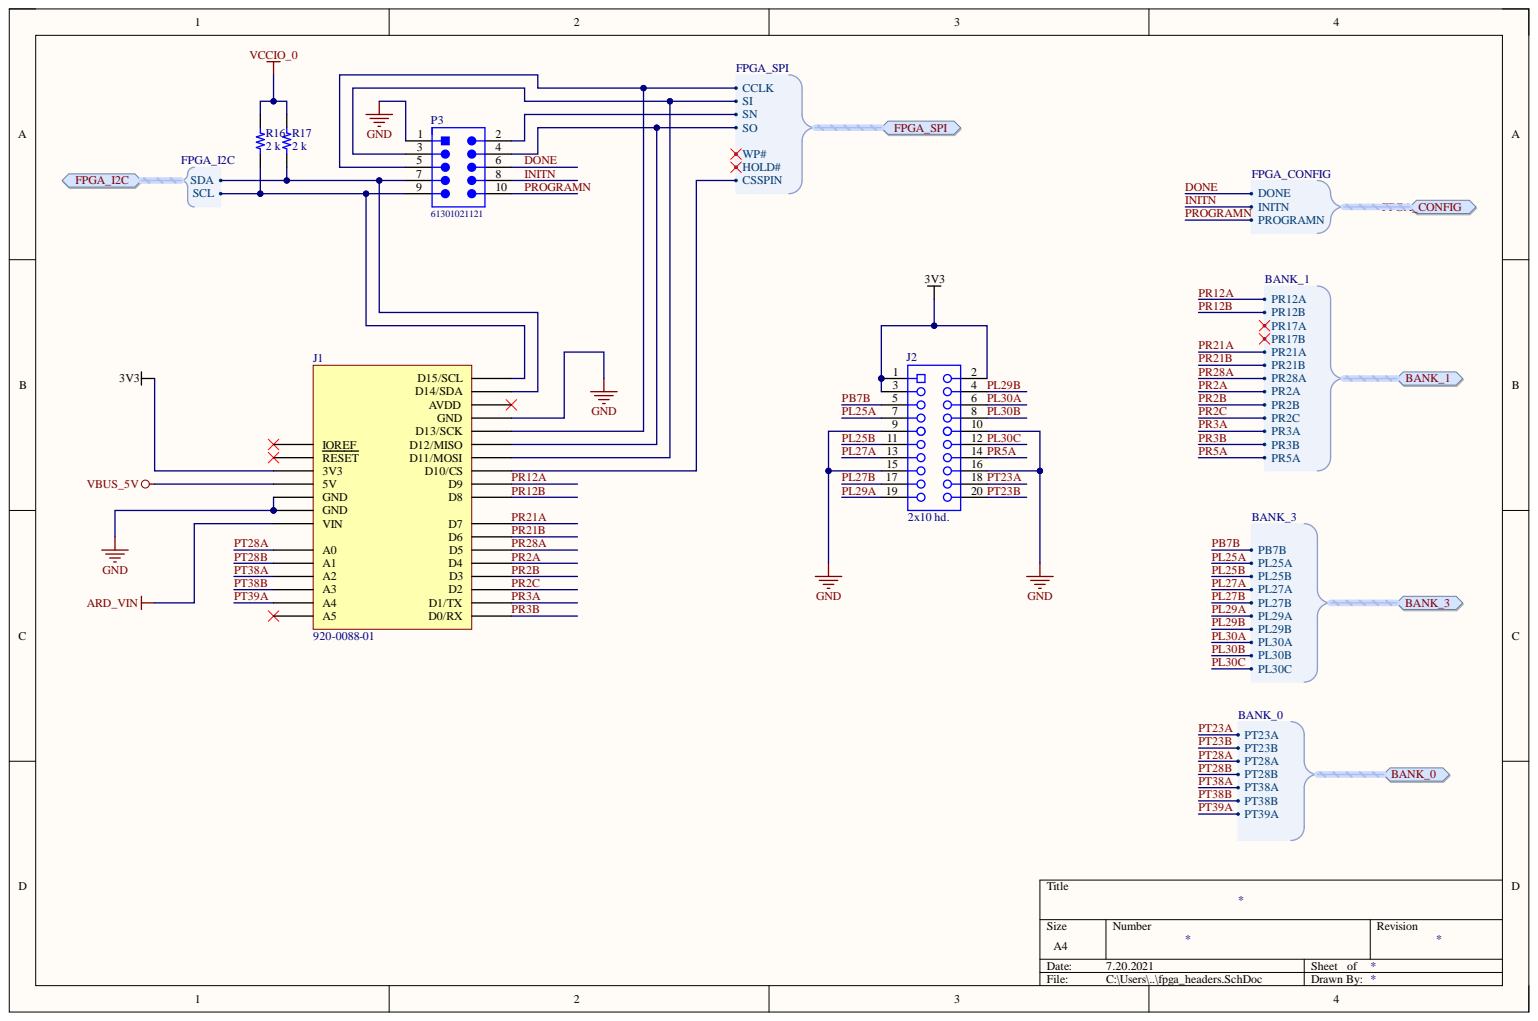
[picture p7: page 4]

DONE INITN

GND

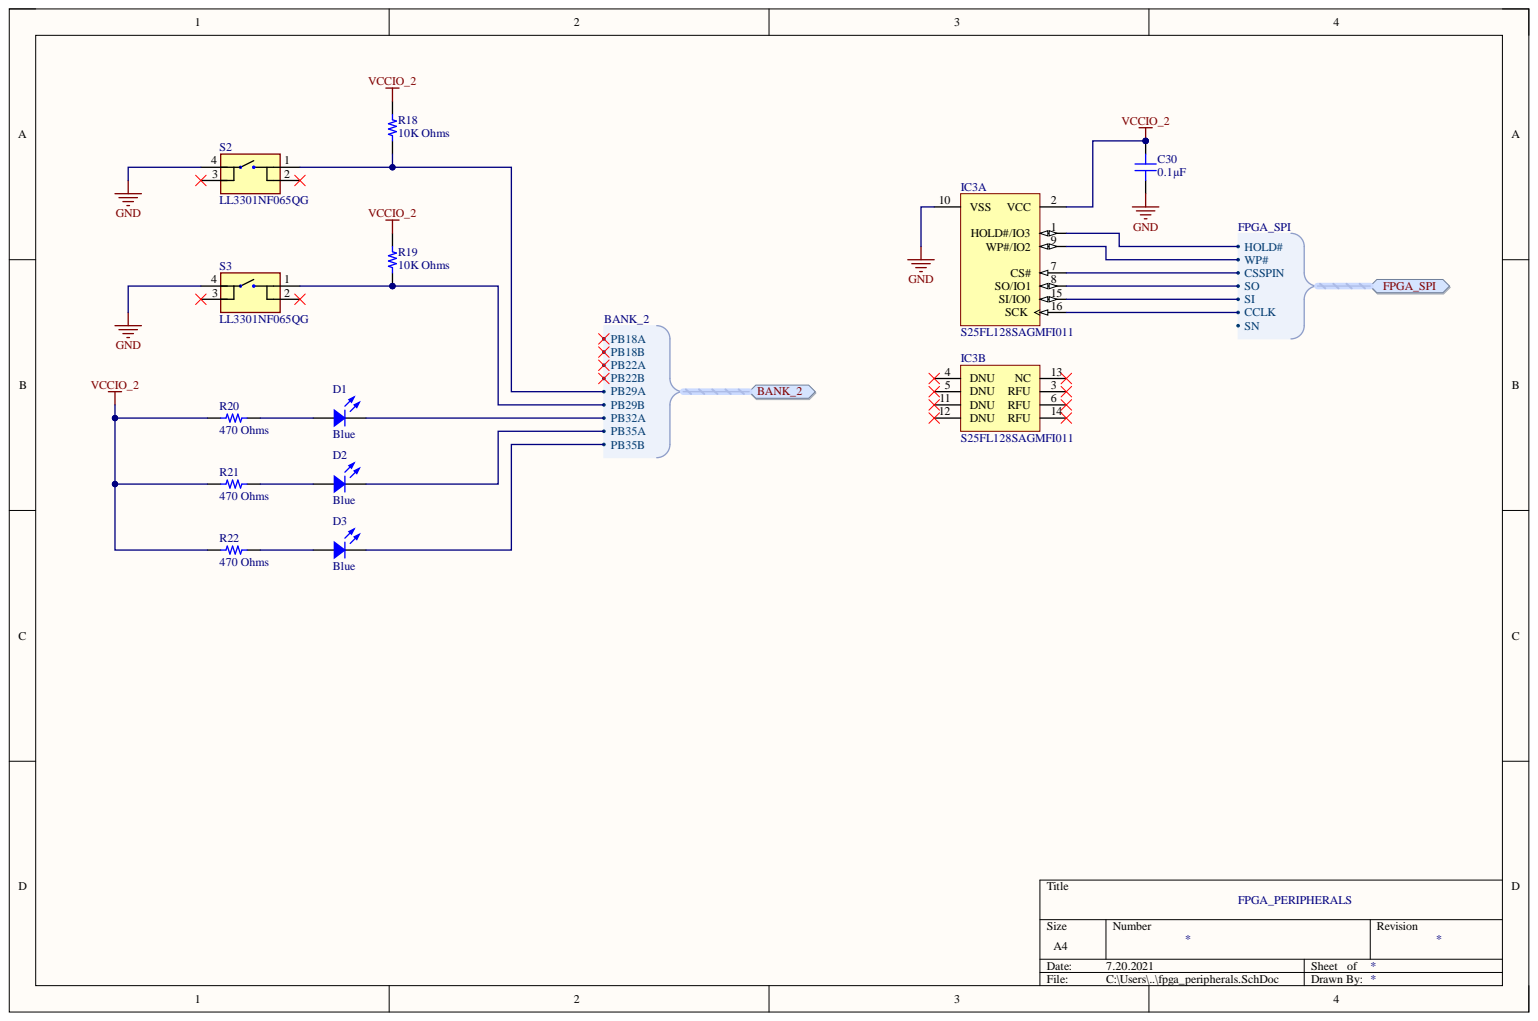
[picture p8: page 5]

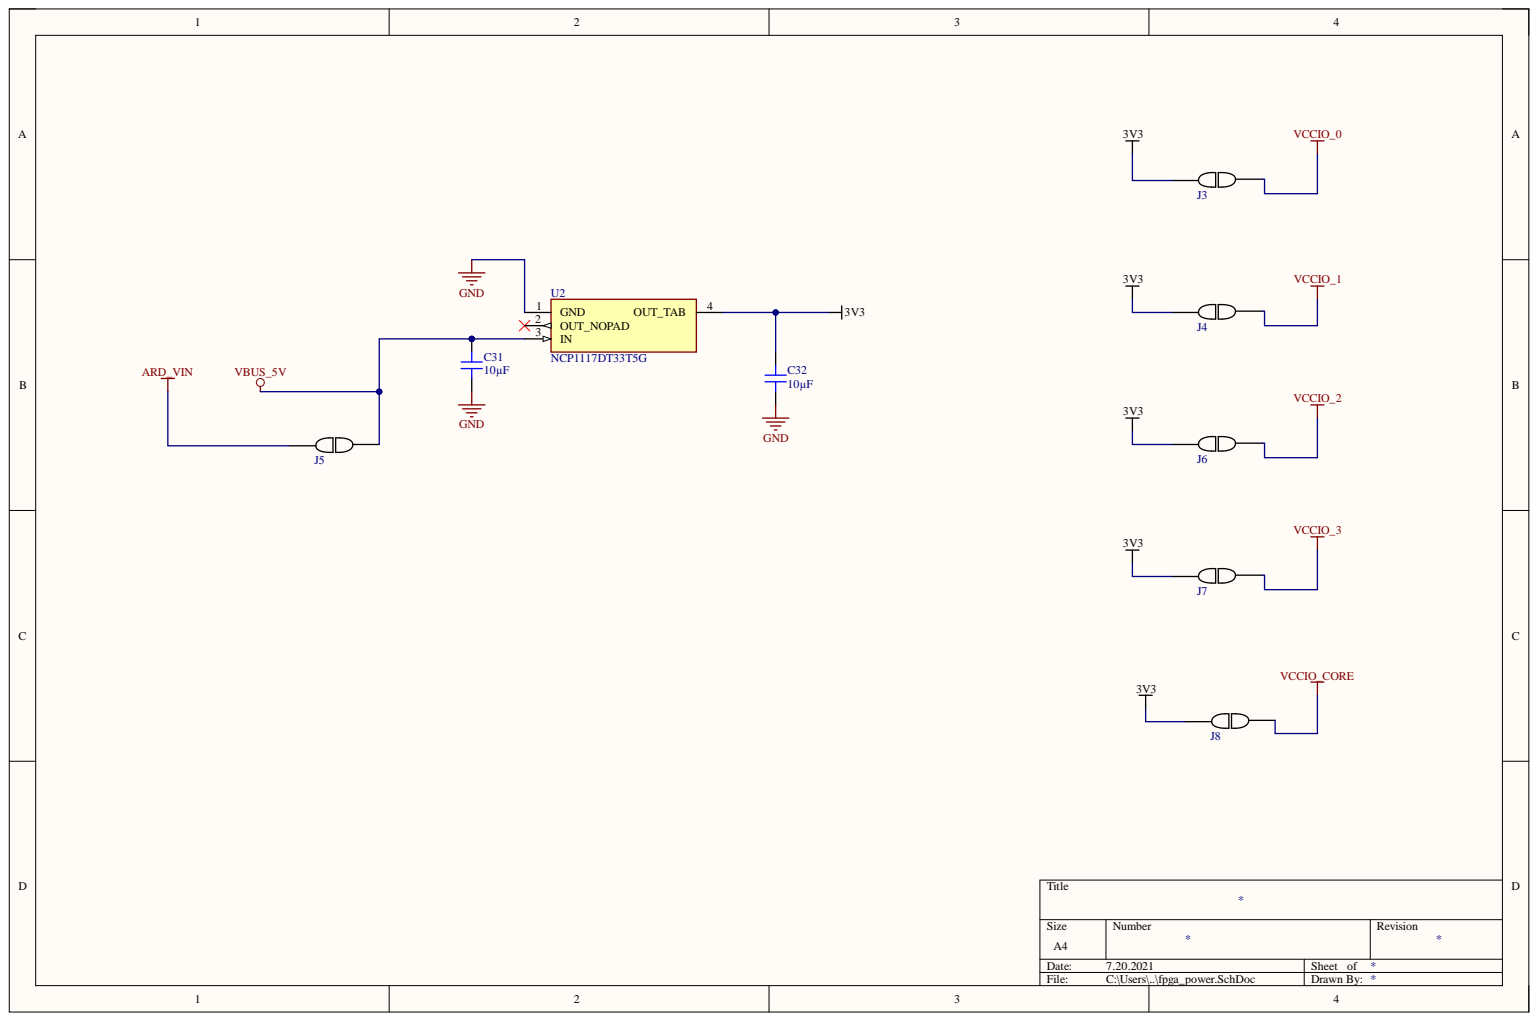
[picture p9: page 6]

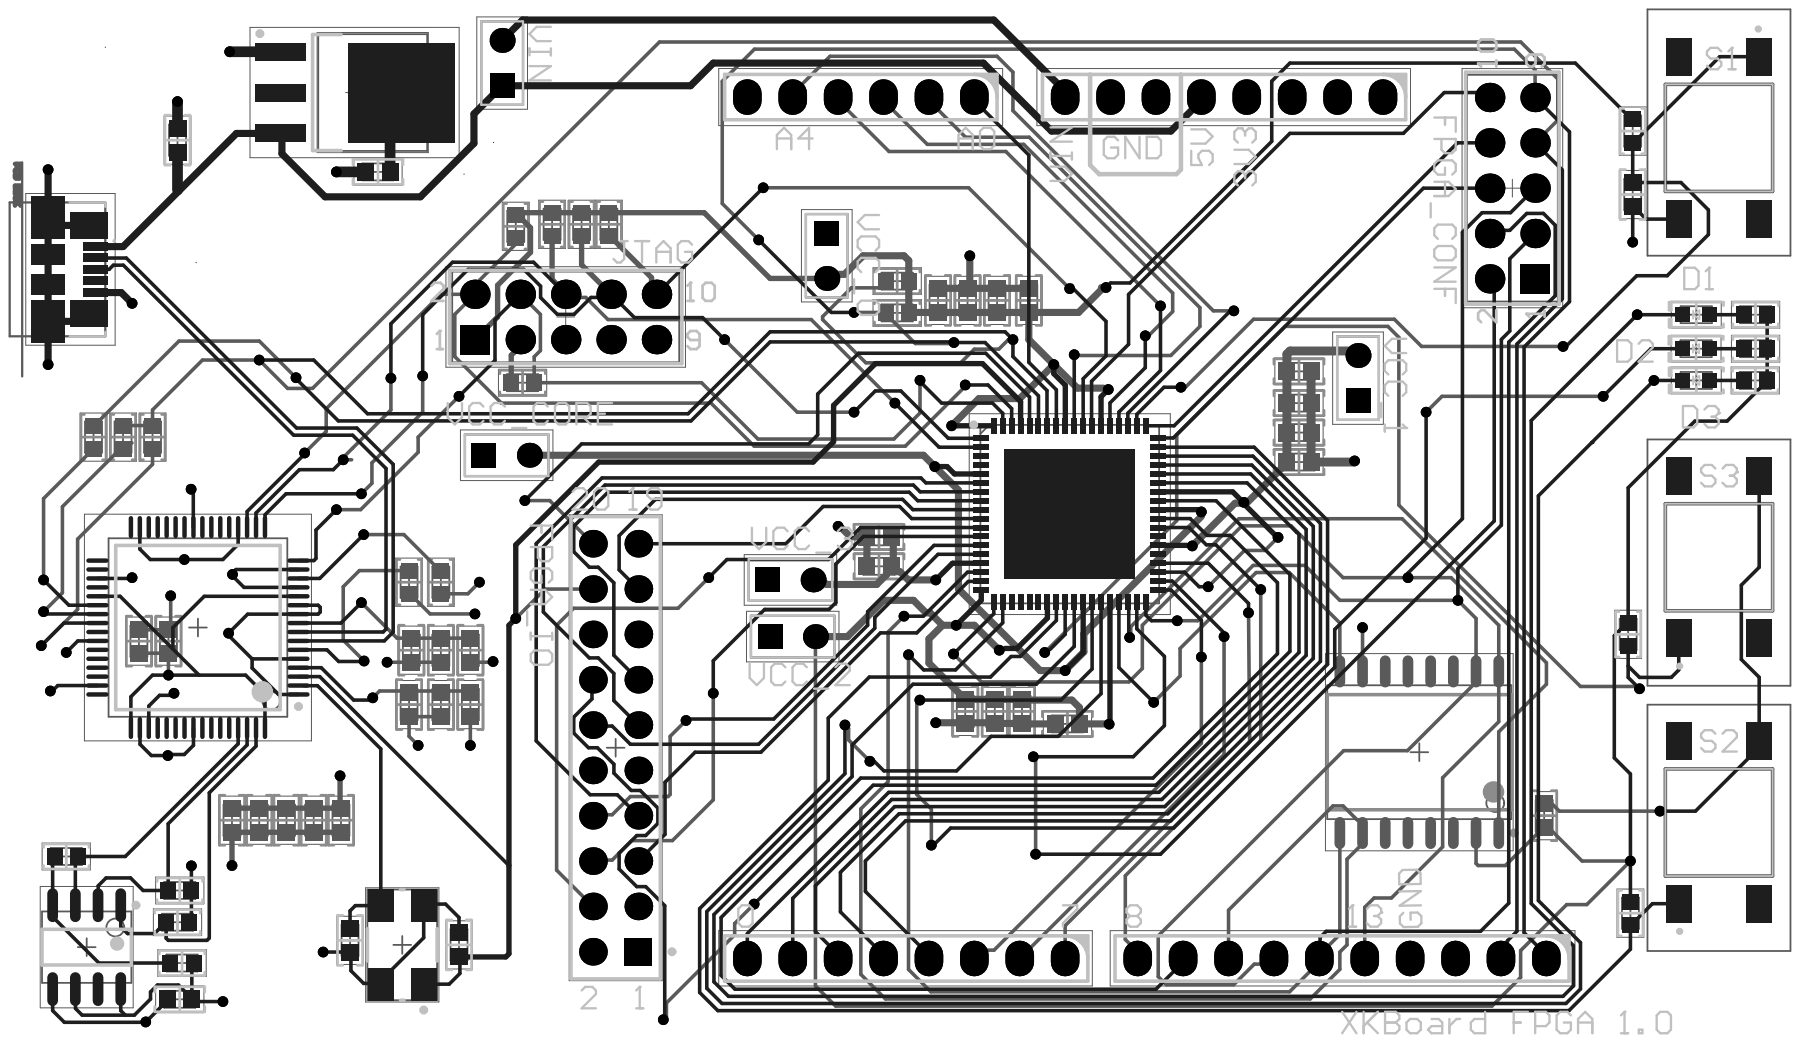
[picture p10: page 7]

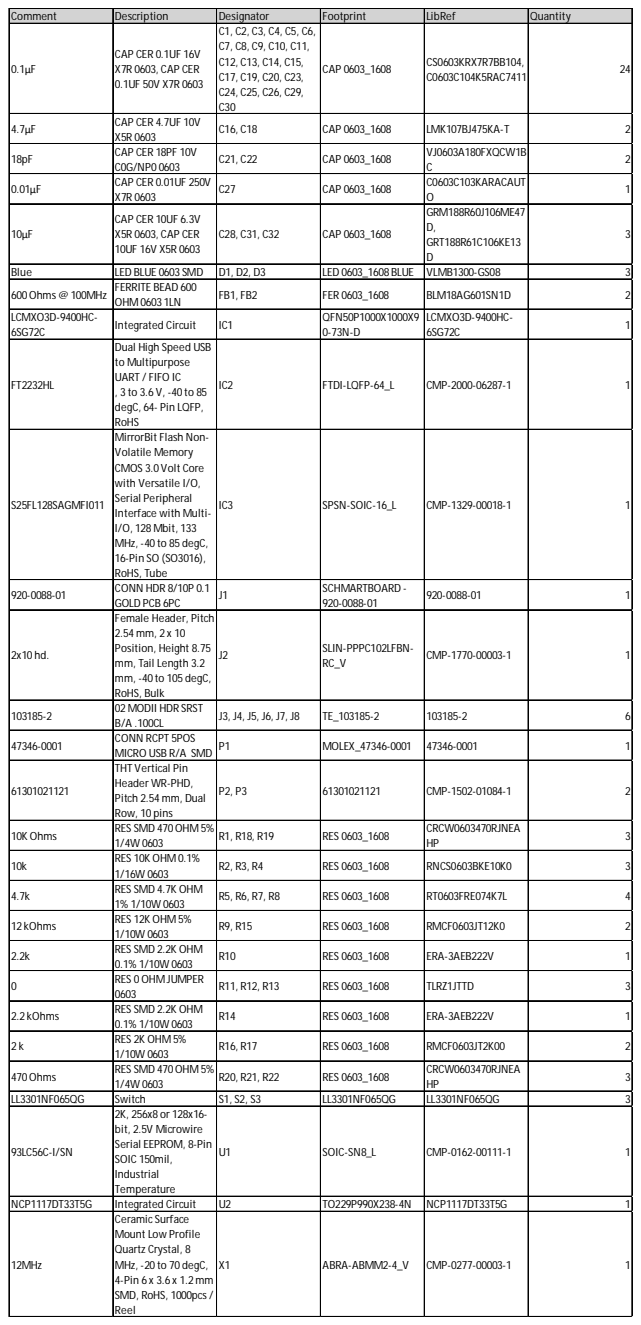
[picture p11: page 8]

Comment | Description | Designator | Footprint | LibRef | Quantity
0.1µF | CAP CER 0.1UF 16V X7R 0603, CAP CER 0.1UF 50V X7R 0603 | C1, C2, C3, C4, C5, C6, C7, C8, C9, C10, C11, C12, C13, C14, C15, C17, C19, C20, C23, C24, C25, C26, C29, C30 | CAP 0603_1608 | CS0603KRX7R7BB104, C0603C104K5RAC7411 | 24

4.7µF | CAP CER 4.7UF 10V X5R 0603 | C16, C18 | CAP 0603_1608 | LMK107BJ475KA-T | 2

18pF | CAP CER 18PF 10V C0G/NP0 0603 | C21, C22 | CAP 0603_1608 | VJ0603A180FXQCW1B C | 2

0.01µF | CAP CER 0.01UF 250V X7R 0603 | C27 | CAP 0603_1608 | C0603C103KARACAUT O | 1

10µF | CAP CER 10UF 6.3V X5R 0603, CAP CER 10UF 16V X5R 0603 | C28, C31, C32 | CAP 0603_1608 | GRM188R60J106ME47 D, GRT188R61C106KE13 D | 3

Blue | LED BLUE 0603 SMD | D1, D2, D3 | LED 0603_1608 BLUE | VLMB1300-GS08 | 3
600Ohms @ 100MHz | FERRITE BEAD 600 OHM 0603 1LN | FB1, FB2 | FER 0603_1608 | BLM18AG601SN1D | 2

LCMXO3D-9400HC-6SG72C | Integrated Circuit | IC1 | QFN50P1000X1000X9 0-73N-D | LCMXO3D-9400HC-6SG72C | 1

FT2232HL | Dual High Speed USB to Multipurpose UART / FIFO IC , 3 to 3.6 V, -40 to 85 degC, 64- Pin LQFP, RoHS | IC2 | FTDI-LQFP-64_L | CMP-2000-06287-1 | 1

S25FL128SAGMFI011 | MirrorBit Flash Non-Volatile Memory CMOS 3.0 Volt Core with Versatile I/O, Serial Peripheral Interface with Multi-I/O, 128 Mbit, 133 MHz, -40 to 85 degC, 16-Pin SO (SO3016), RoHS, Tube | IC3 | SPSN-SOIC-16_L | CMP-1329-00018-1 | 1

920-0088-01 | CONN HDR 8/10P 0.1 GOLD PCB 6PC | J1 | SCHMARTBOARD -920-0088-01 | 920-0088-01 | 1

2x10 hd. | Female Header, Pitch 2.54mm, 2 x 10 Position, Height 8.75 mm, Tail Length 3.2 mm, -40 to 105 degC, RoHS, Bulk | J2 | SLIN-PPPC102LFBN-RC_V | CMP-1770-00003-1 | 1

103185-2 | 02 MODII HDR SRST B/A .100CL | J3, J4, J5, J6, J7, J8 | TE_103185-2 | 103185-2 | 6

47346-0001 | CONN RCPT 5POS MICRO USB R/A SMD | P1 | MOLEX_47346-0001 | 47346-0001 | 1

61301021121 | THT Vertical Pin Header WR-PHD, Pitch 2.54mm, Dual Row, 10 pins | P2, P3 | 61301021121 | CMP-1502-01084-1 | 2

10K Ohms | RES SMD 470OHM 5% 1/4W 0603 | R1, R18, R19 | RES 0603_1608 | CRCW0603470RJNEA HP | 3

10k | RES 10K OHM 0.1% 1/16W 0603 | R2, R3, R4 | RES 0603_1608 | RNCS0603BKE10K0 | 3

4.7k | RES SMD 4.7K OHM 1% 1/10W 0603 | R5, R6, R7, R8 | RES 0603_1608 | RT0603FRE074K7L | 4

12 kOhms | RES 12K OHM 5% 1/10W 0603 | R9, R15 | RES 0603_1608 | RMCF0603JT12K0 | 2

2.2k | RES SMD 2.2K OHM 0.1% 1/10W 0603 | R10 | RES 0603_1608 | ERA-3AEB222V | 1

0 | RES 0OHM JUMPER 0603 | R11, R12, R13 | RES 0603_1608 | TLRZ1JTTD | 3

2.2 kOhms | RES SMD 2.2K OHM 0.1% 1/10W 0603 | R14 | RES 0603_1608 | ERA-3AEB222V | 1

2 k | RES 2K OHM 5% 1/10W 0603 | R16, R17 | RES 0603_1608 | RMCF0603JT2K00 | 2

470Ohms | RES SMD 470OHM 5% 1/4W 0603 | R20, R21, R22 | RES 0603_1608 | CRCW0603470RJNEA HP | 3

LL3301NF065QG | Switch | S1, S2, S3 | LL3301NF065QG | LL3301NF065QG | 3
93LC56C-I/SN | 2K, 256x8 or 128x16-bit, 2.5V Microwire Serial EEPROM, 8-Pin SOIC 150mil, Industrial Temperature | U1 | SOIC-SN8_L | CMP-0162-00111-1 | 1

NCP1117DT33T5G | Integrated Circuit | U2 | TO229P990X238-4N | NCP1117DT33T5G | 1
12MHz | Ceramic Surface Mount Low Profile Quartz Crystal, 8 MHz, -20 to 70 degC, 4-Pin 6 x 3.6 x 1.2mm SMD, RoHS, 1000pcs / Reel | X1 | ABRA-ABMM2-4_V | CMP-0277-00003-1 | 1

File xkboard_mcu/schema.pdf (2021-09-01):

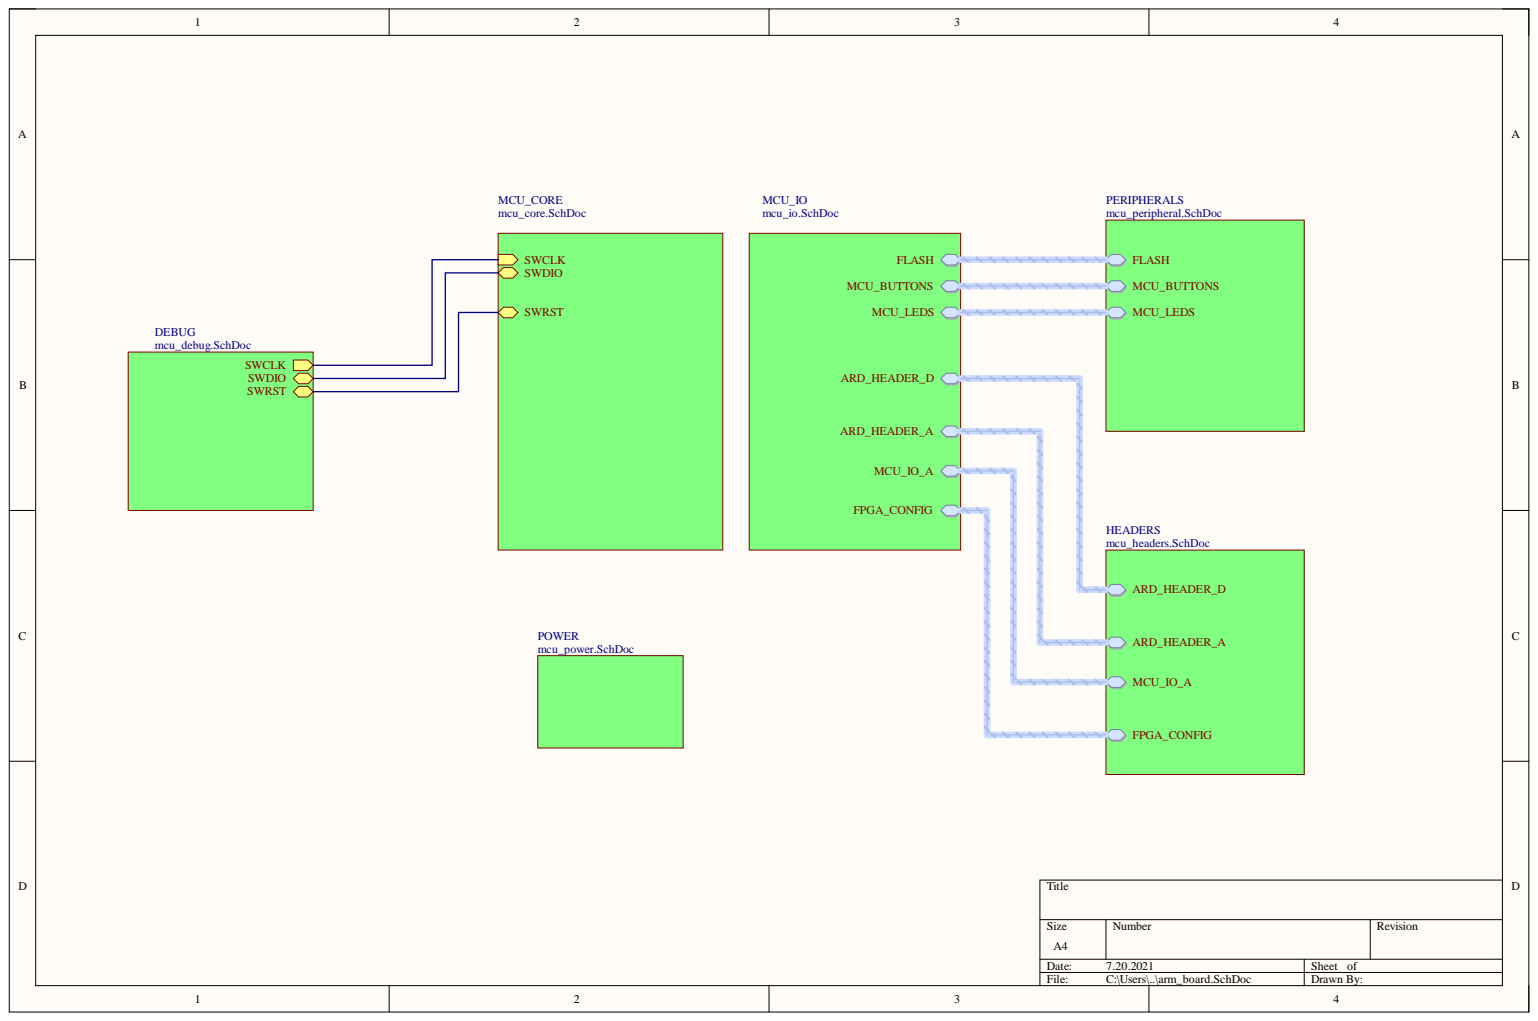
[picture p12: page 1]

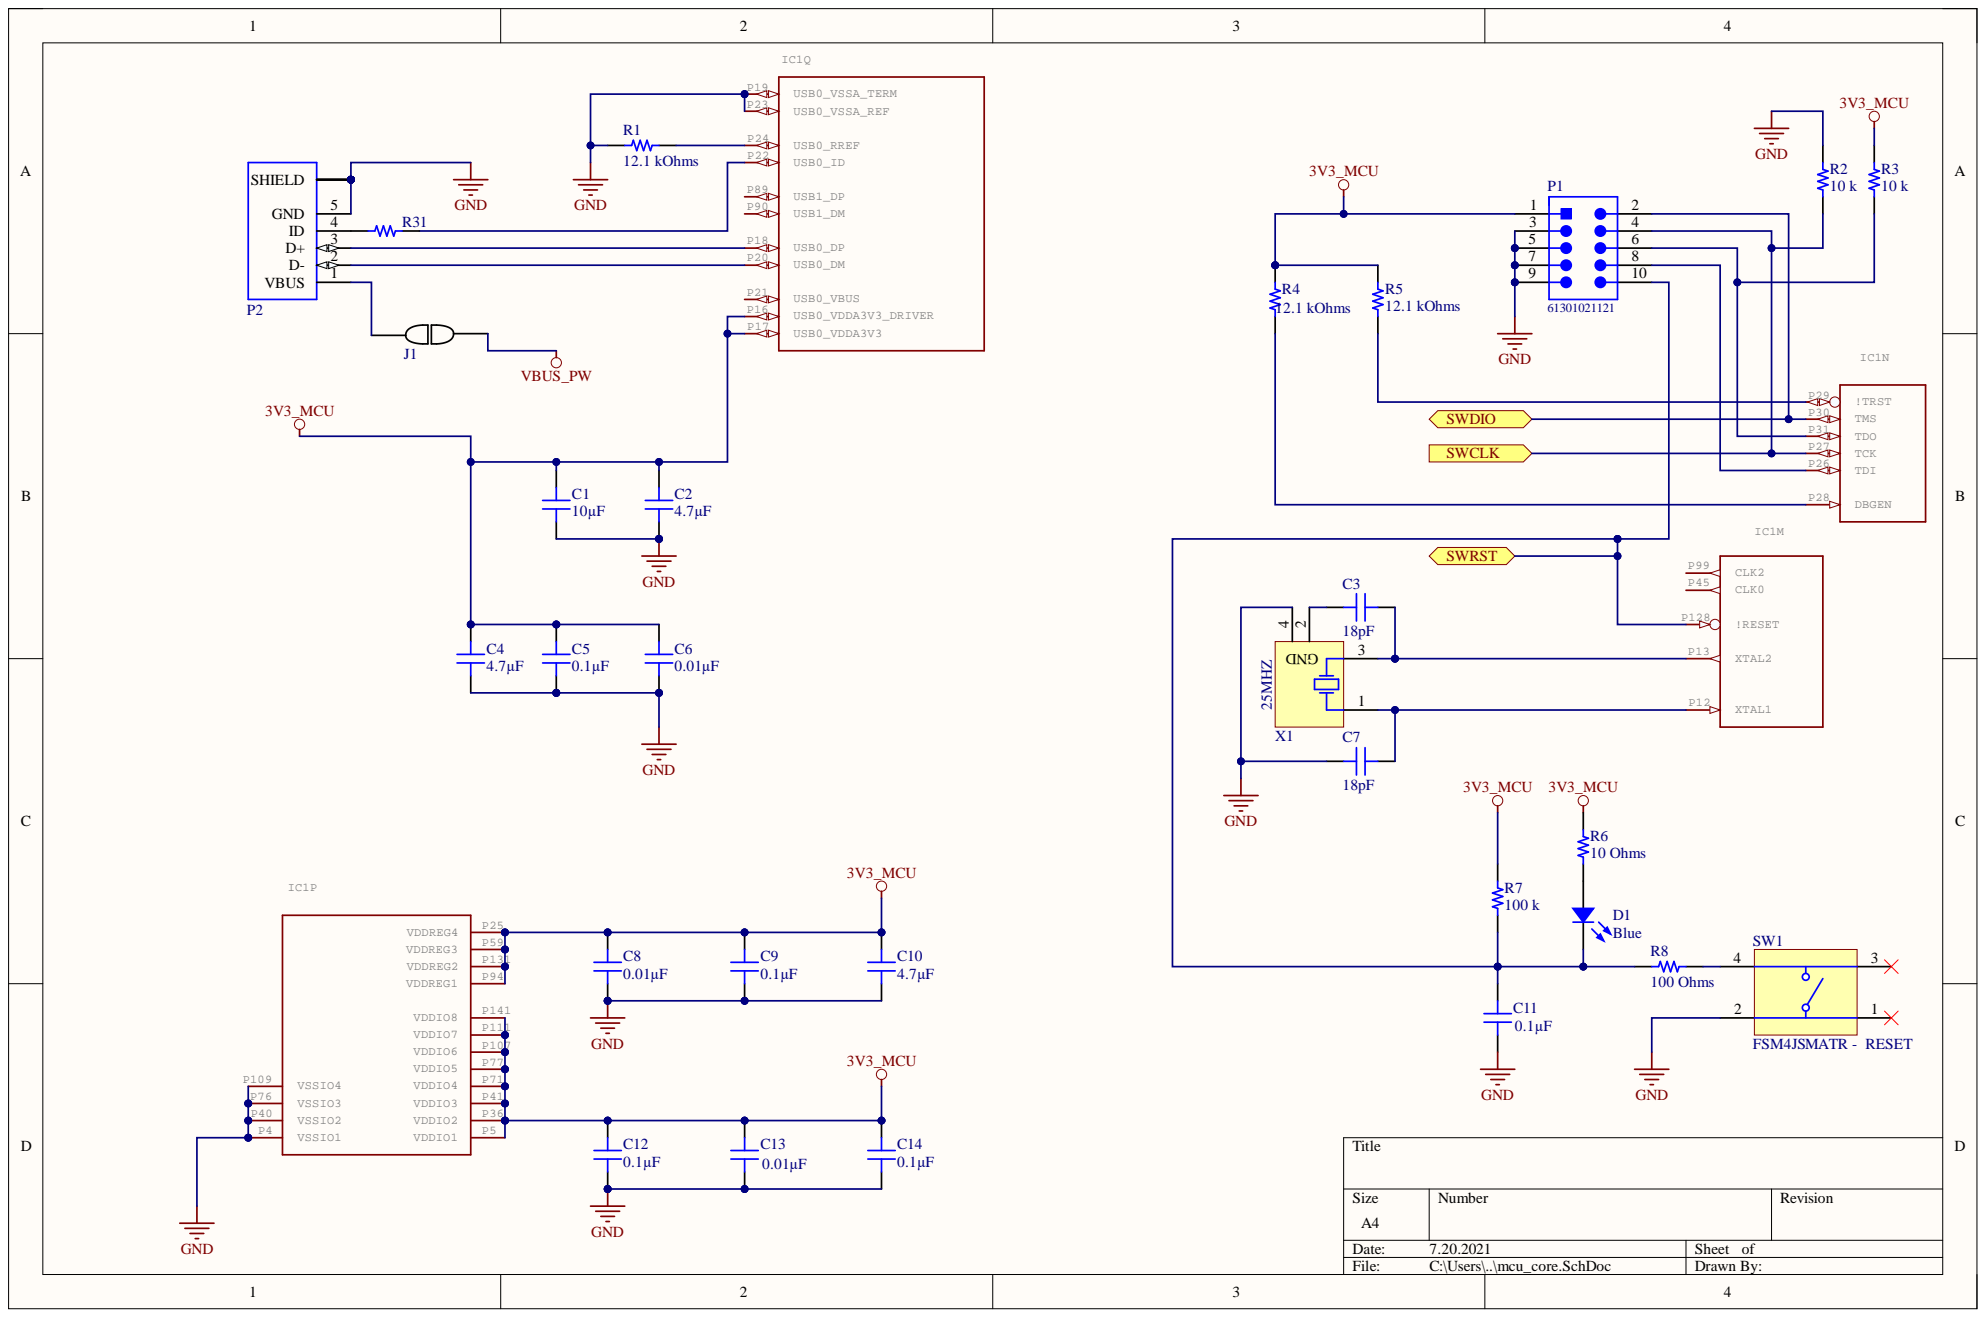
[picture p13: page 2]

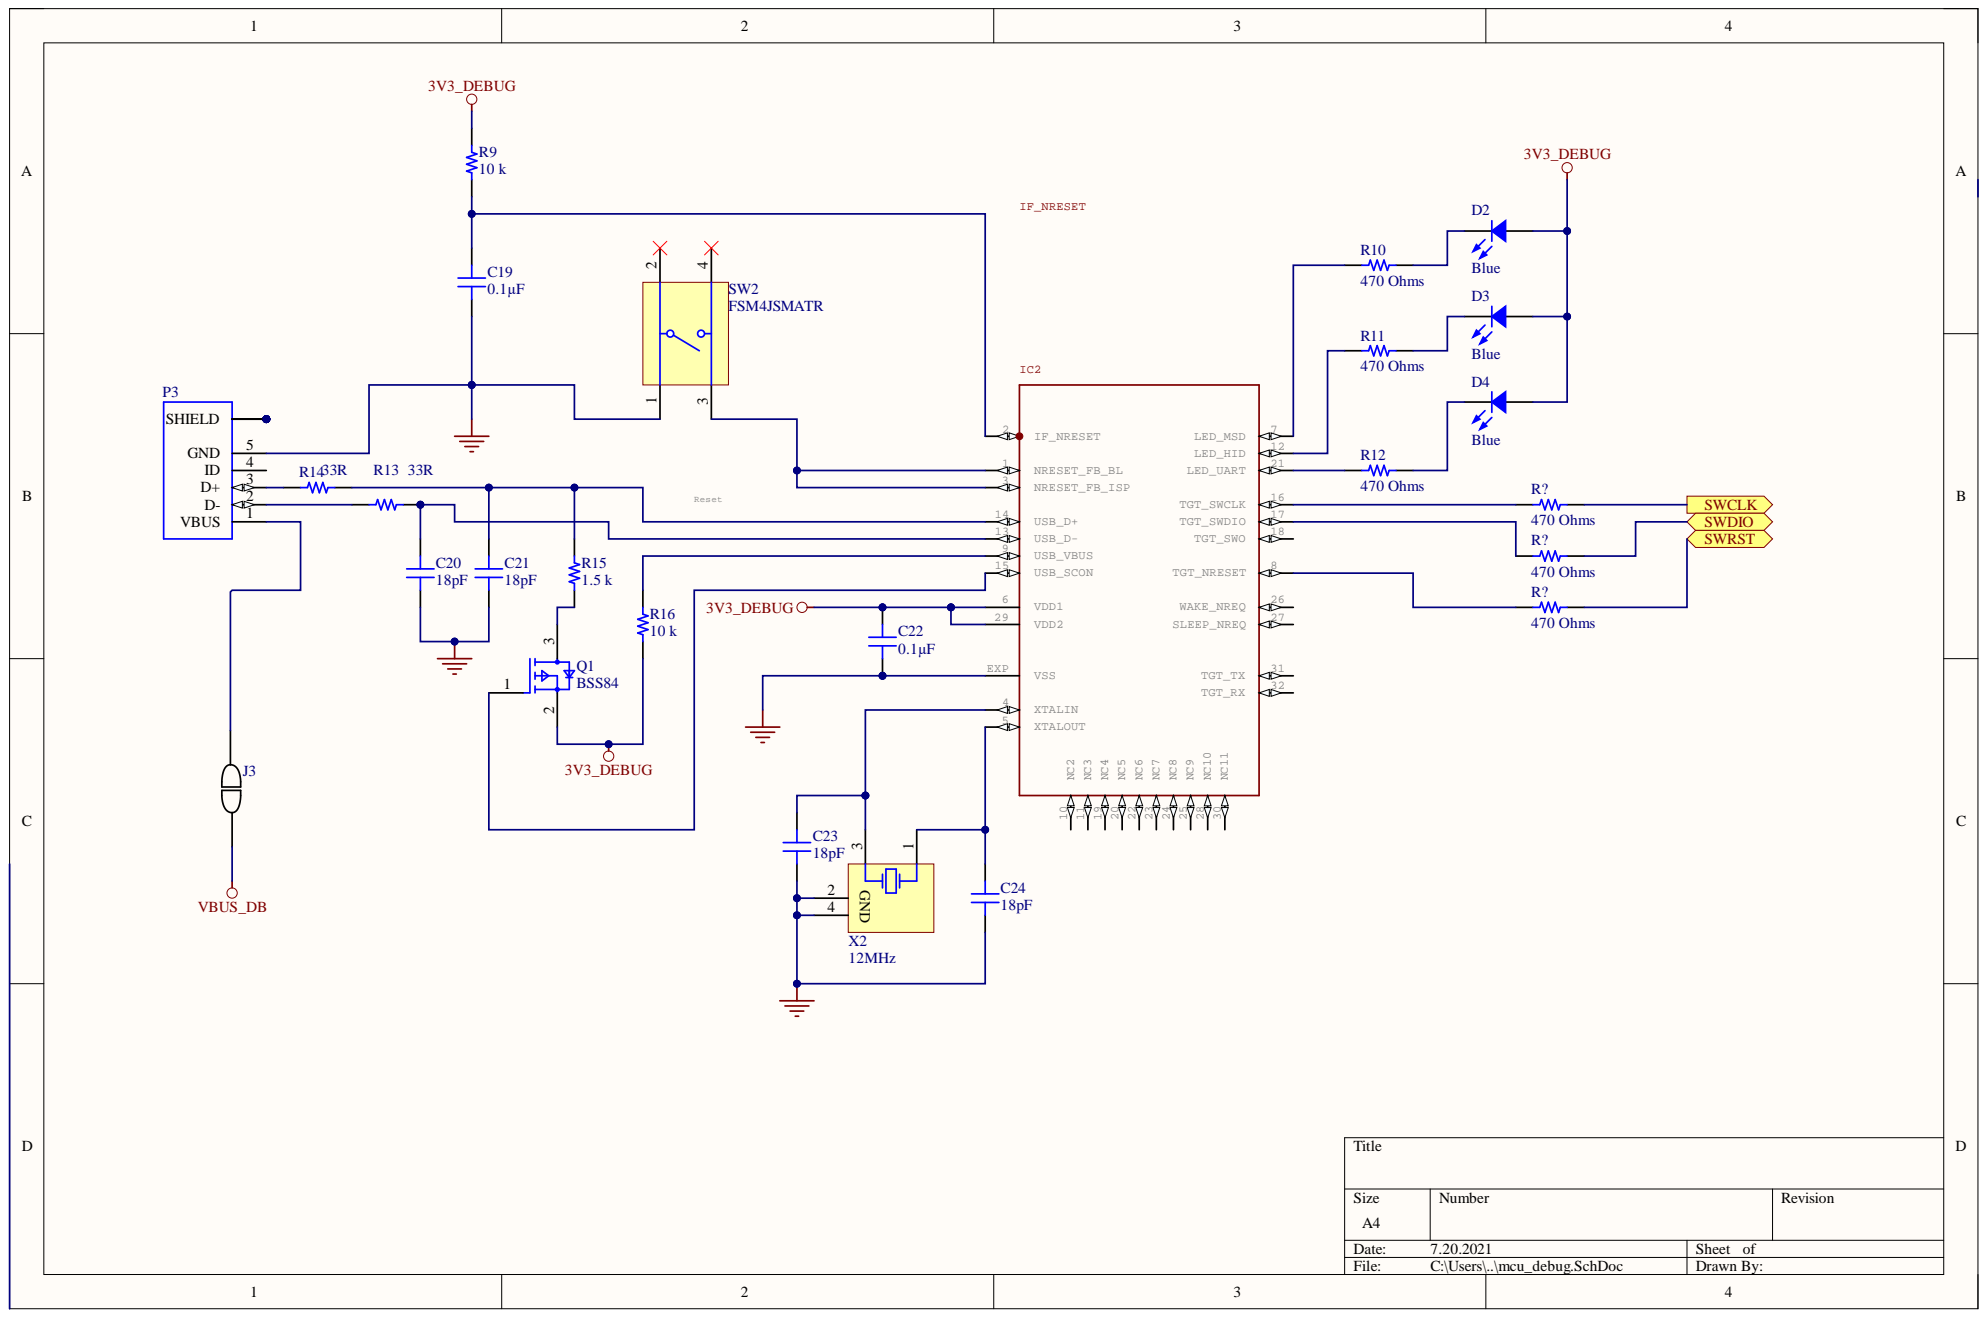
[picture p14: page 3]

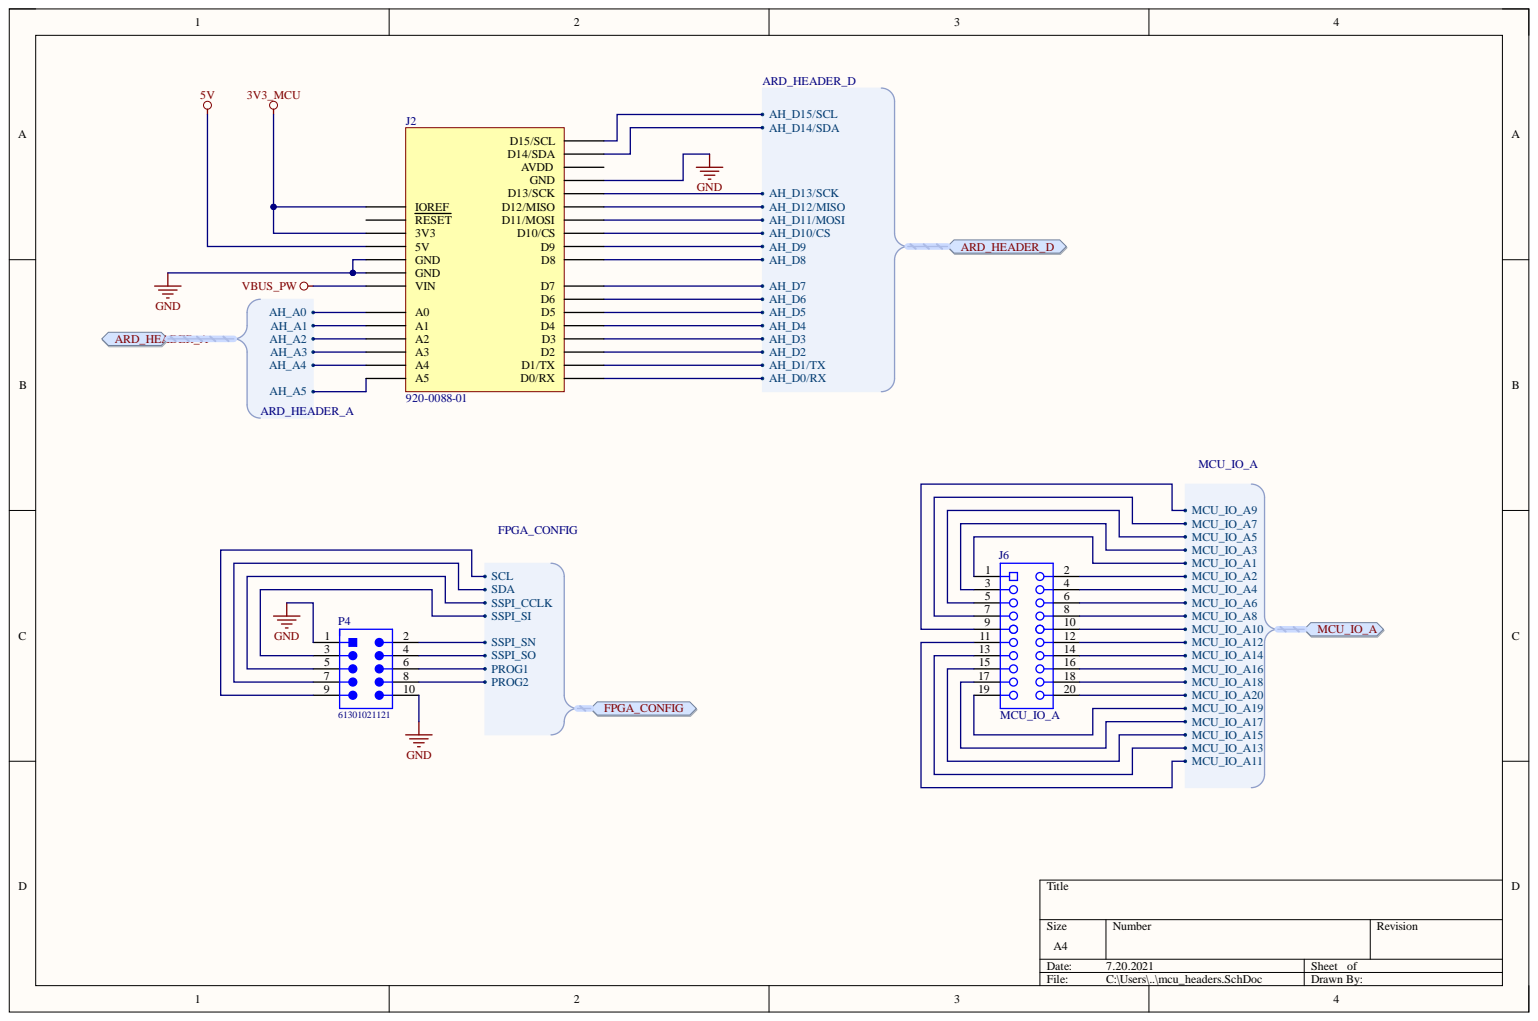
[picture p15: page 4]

15 | 16
17 | 18
19 | 20


P5_4 P5_5 P5_6 P5_7 | P57
P58
P63
P65

BOOT1_2
BOOT2_8
BOOT2_9





Comment | Description | Designator | Footprint | LibRef | Quantity
10µF | CAP CER 10UF 10V X5R 0603, CAP CER 10UF 16V X5R 0603 | C1, C16, C18 | CAP 0603_1608 | GRM188R61A106MAA LD, GRT188R61C106KE13 D

4.7µF | CAP CER 4.7UF 10V X5R 0603 | C2, C4, C10 | CAP 0603_1608 | LMK107BJ475KA-T | 3

18pF | CAP CER 18PF 10V C0G/NP0 0603 | C3, C7, C20, C21, C23, C24 | CAP 0603_1608 | VJ0603A180FXQCW1B C | 6

0.1µF | CAP CER 0.1UF 50V X7R 0603, CAP CER 0.1UF 10V X7R 0603, CAP CER 0.1UF 16V X7R 0603 | C5, C9, C11, C12, C14, C17, C19, C22, C25, C26 | CAP 0603_1608 | C0603C104K5RAC7411 , C0603T104K8RAC7867 , CS0603KRX7R7BB104 | 10

0.01µF | CAP CER 0.01UF 250V X7R 0603 | C6, C8, C13 | CAP 0603_1608 | C0603C103KARACAUT O | 3

1µF | CAP CER 0603 1UF 16V X7R 20% | C15 | CAP 0603_1608 | C0603X105M4RACAU TO | 1

Blue | LED BLUE 0603 SMD | D1, D2, D3, D4, D5, D6, D7 | LED 0603_1608 BLUE | VLMB1300-GS08 | 7

600Ohms @ 100MHz | FERRITE BEAD 600 OHM 0603 1LN | FB1 | FER 0603_1608 | BLM18AG601SN1D | 1

LQFP144 - SOT486-1 LQFP144: plastic low profile quad flat package; 144 leads; body 20 x 20 x 1.4mm body + leads 22 x 22 mm Solderland (pads) 0.4 x 1.5mm on corners (8 x) and 0.28 x 1.5mm (136 x) | | IC1 | LQFP144 | LPC4300_LQFP144 | 1

CMSIS-DAP Interface : 32-bit LPC11U00 ARM Cortex M3 RISC 64KB Flash 2.5V/3.3V 33-Pin HVQFN EP | | IC2 | HVQFN33 | IF_LPC11U35FHI33/50 1 | 1

103185-2 | 02 MODII HDR SRST B/A .100CL | J1, J3, J4 | TE_103185-2 | 103185-2 | 3

920-0088-01 | CONN HDR 8/10P 0.1 GOLD PCB 6PC | J2 | SCHMARTBOARD -920-0088-01 | 920-0088-01 | 1

MCU_IO_A | Female Header, Pitch 2.54mm, 2 x 10 Position, Height 8.75 mm, Tail Length 3.2 mm, -40 to 105 degC, RoHS, Bulk | J6 | SLIN-PPPC102LFBN-RC_V | CMP-1770-00003-1 | 1

150060RS75000 | SMD mono-color Chip LED, WL-SMCW, Red | LED1 | 0603_A | CMP-1426-00001-1 | 1

61301021121 | THT Vertical Pin Header WR-PHD, Pitch 2.54mm, Dual Row, 10 pins | P1, P4 | 61301021121 | CMP-1502-01084-1 | 2

47346-0001 | CONN RCPT 5POS MICRO USB R/A SMD | P2, P3 | MOLEX_47346-0001 | 47346-0001 | 2

BSS84 | MOSFET P-CH 50V 130MA SOT-23 | Q1 | FP-SOT23-MFG | CMP-14409-000006-1 | 1

12.1 kOhms | RES SMD 12.1K OHM 1% 1/10W 0603 | R1, R4, R5 | RES 0603_1608 | CR0603-FX-1212ELF | 3

10 k | RES 10K OHM 0.1% 1/16W 0603 | R2, R3, R9, R16 | RES 0603_1608 | RNCS0603BKE10K0 | 4

10Ohms | RES SMD 10OHM 0.1% 1/10W 0603 | R6 | RES 0603_1608 | CRT0603-BY-10R0ELF | 1

100 k | RES 100K OHM 5% 1/10W 0603 | R7 | RES 0603_1608 | RMCF0603JT100K | 1

100Ohms | RES 100OHM 0.1% 1/16W 0603 | R8, R22 | RES 0603_1608 | RNCS0603BKE100R | 2

470Ohms | RES SMD 470OHM 5% 1/4W 0603 | R10, R11, R12, R19, R20, R21, R? | RES 0603_1608 | CRCW0603470RJNEA HP | 9

33R | RES SMD 33OHM 0.1% 1/16W 0603 | R13, R14 | RES 0603_1608 | CPF0603B33RE | 2

1.5 k | CRGP 0603 1K5 1% | R15 | RES 0603_1608 | CRGP0603F1K5 | 1
10K Ohms | RES SMD 470OHM 5% 1/4W 0603 | R17, R18 | RES 0603_1608 | CRCW0603470RJNEA HP | 2

2.2 k | RES SMD 2.2K OHM 1% 1/10W 0603, RES 2.2K OHM 5% 1/10W 0603 | R23, R24, R25, R26, R27, R28, R29, R30 | RES 0603_1608 | ERJ-3EKF2201V, RK73B1JTTD222J | 8

Value | RES 0OHM JUMPER 0603 | R31 | RES 0603_1608 | TLRZ1JTTD | 1

FSM4JSMATR - RESET | Micro Miniature Push Button Switch FSM JSM, 50mA, -35 to 85 degC, 4-Pin SMD, RoHS, Tape and Reel | SW1 | TECO-FSM4JSMATR_V | CMP-2000-07486-1 | 1

FSM4JSMATR | Micro Miniature Push Button Switch FSM JSM, 50mA, -35 to 85 degC, 4-Pin SMD, RoHS, Tape and Reel | SW2, SW3, SW4, SW5 | TECO-FSM4JSMATR_V | CMP-2000-07486-1 | 4

TC1017-3.3VCTTR | 150mA, Tiny CMOS LDO with Shutdown, 5-Pin SOT-23, Extended Temperature, Tape and Reel | U1 | SOT-23-CT5_L | CMP-0136-00743-1 | 1

TPS77733DR | Single Output Fast Transient Response LDO, 750mA, Fixed 3.3 V Output, 2.7 to 10 V Input, 8-pin SOIC (D), -40 to 125 degC, Green (RoHS & no Sb/Br) | U2 | D0008A_N | CMP-0395-00062-2 | 1

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

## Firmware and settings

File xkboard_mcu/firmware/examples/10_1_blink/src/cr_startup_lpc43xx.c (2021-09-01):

//*****************************************************************************
// LPC43xx (Cortex-M4) Microcontroller Startup code for use with LPCXpresso IDE
//
// Version : 150706
//*****************************************************************************
//
// Copyright(C) NXP Semiconductors, 2013-2015, 2020
// All rights reserved.
//
// NXP Confidential. This software is owned or controlled by NXP and may only be 
// used strictly in accordance with the applicable license terms.  
//
// By expressly accepting such terms or by downloading, installing, activating 
// and/or otherwise using the software, you are agreeing that you have read, and 
// that you agree to comply with and are bound by, such license terms.  
// 
// If you do not agree to be bound by the applicable license terms, then you may not 
// retain, install, activate or otherwise use the software.
//*****************************************************************************

#if defined (__cplusplus)
#ifdef __REDLIB__
#error Redlib does not support C++
#else
//*****************************************************************************
//
// The entry point for the C++ library startup
//
//*****************************************************************************
extern "C" {
    extern void __libc_init_array(void);
}
#endif
#endif

#define WEAK __attribute__ ((weak))
#define ALIAS(f) __attribute__ ((weak, alias (#f)))

//*****************************************************************************
#if defined (__cplusplus)
extern "C" {
#endif

//*****************************************************************************
#if defined (__USE_CMSIS) || defined (__USE_LPCOPEN)
// Declaration of external SystemInit function
extern void SystemInit(void);
#endif

//*****************************************************************************
//
// Forward declaration of the default handlers. These are aliased.
// When the application defines a handler (with the same name), this will 
// automatically take precedence over these weak definitions
//
//*****************************************************************************
void ResetISR(void);
WEAK void NMI_Handler(void);
WEAK void HardFault_Handler(void);
WEAK void MemManage_Handler(void);
WEAK void BusFault_Handler(void);
WEAK void UsageFault_Handler(void);
WEAK void SVC_Handler(void);
WEAK void DebugMon_Handler(void);
WEAK void PendSV_Handler(void);
WEAK void SysTick_Handler(void);
WEAK void IntDefaultHandler(void);

//*****************************************************************************
//
// Forward declaration of the specific IRQ handlers. These are aliased
// to the IntDefaultHandler, which is a 'forever' loop. When the application
// defines a handler (with the same name), this will automatically take 
// precedence over these weak definitions
//
//*****************************************************************************
void DAC_IRQHandler(void) ALIAS(IntDefaultHandler);
#if defined (__USE_LPCOPEN)
void M0APP_IRQHandler(void) ALIAS(IntDefaultHandler);
#else
void M0CORE_IRQHandler(void) ALIAS(IntDefaultHandler);
#endif
void DMA_IRQHandler(void) ALIAS(IntDefaultHandler);
void FLASH_EEPROM_IRQHandler(void) ALIAS(IntDefaultHandler);
void ETH_IRQHandler(void) ALIAS(IntDefaultHandler);
void SDIO_IRQHandler(void) ALIAS(IntDefaultHandler);
void LCD_IRQHandler(void) ALIAS(IntDefaultHandler);
void USB0_IRQHandler(void) ALIAS(IntDefaultHandler);
void USB1_IRQHandler(void) ALIAS(IntDefaultHandler);
void SCT_IRQHandler(void) ALIAS(IntDefaultHandler);
void RIT_IRQHandler(void) ALIAS(IntDefaultHandler);
void TIMER0_IRQHandler(void) ALIAS(IntDefaultHandler);
void TIMER1_IRQHandler(void) ALIAS(IntDefaultHandler);
void TIMER2_IRQHandler(void) ALIAS(IntDefaultHandler);
void TIMER3_IRQHandler(void) ALIAS(IntDefaultHandler);
void MCPWM_IRQHandler(void) ALIAS(IntDefaultHandler);
void ADC0_IRQHandler(void) ALIAS(IntDefaultHandler);
void I2C0_IRQHandler(void) ALIAS(IntDefaultHandler);
void SPI_IRQHandler(void) ALIAS(IntDefaultHandler);
void I2C1_IRQHandler(void) ALIAS(IntDefaultHandler);
void ADC1_IRQHandler(void) ALIAS(IntDefaultHandler);
void SSP0_IRQHandler(void) ALIAS(IntDefaultHandler);
void SSP1_IRQHandler(void) ALIAS(IntDefaultHandler);
void UART0_IRQHandler(void) ALIAS(IntDefaultHandler);
void UART1_IRQHandler(void) ALIAS(IntDefaultHandler);
void UART2_IRQHandler(void) ALIAS(IntDefaultHandler);
void UART3_IRQHandler(void) ALIAS(IntDefaultHandler);
void I2S0_IRQHandler(void) ALIAS(IntDefaultHandler);
void I2S1_IRQHandler(void) ALIAS(IntDefaultHandler);
void SPIFI_IRQHandler(void) ALIAS(IntDefaultHandler);
void SGPIO_IRQHandler(void) ALIAS(IntDefaultHandler);
void GPIO0_IRQHandler(void) ALIAS(IntDefaultHandler);
void GPIO1_IRQHandler(void) ALIAS(IntDefaultHandler);
void GPIO2_IRQHandler(void) ALIAS(IntDefaultHandler);
void GPIO3_IRQHandler(void) ALIAS(IntDefaultHandler);
void GPIO4_IRQHandler(void) ALIAS(IntDefaultHandler);
void GPIO5_IRQHandler(void) ALIAS(IntDefaultHandler);
void GPIO6_IRQHandler(void) ALIAS(IntDefaultHandler);
void GPIO7_IRQHandler(void) ALIAS(IntDefaultHandler);
void GINT0_IRQHandler(void) ALIAS(IntDefaultHandler);
void GINT1_IRQHandler(void) ALIAS(IntDefaultHandler);
void EVRT_IRQHandler(void) ALIAS(IntDefaultHandler);
void CAN1_IRQHandler(void) ALIAS(IntDefaultHandler);
#if defined (__USE_LPCOPEN)
void ADCHS_IRQHandler(void) ALIAS(IntDefaultHandler);
#else
void VADC_IRQHandler(void) ALIAS(IntDefaultHandler);
#endif
void ATIMER_IRQHandler(void) ALIAS(IntDefaultHandler);
void RTC_IRQHandler(void) ALIAS(IntDefaultHandler);
void WDT_IRQHandler(void) ALIAS(IntDefaultHandler);
void M0SUB_IRQHandler(void) ALIAS(IntDefaultHandler);
void CAN0_IRQHandler(void) ALIAS(IntDefaultHandler);
void QEI_IRQHandler(void) ALIAS(IntDefaultHandler);

//*****************************************************************************
//
// The entry point for the application.
// __main() is the entry point for Redlib based applications
// main() is the entry point for Newlib based applications
//
//*****************************************************************************
#if defined (__REDLIB__)
extern void __main(void);
#endif
extern int main(void);
//*****************************************************************************
//
// External declaration for the pointer to the stack top from the Linker Script
//
//*****************************************************************************
extern void _vStackTop(void);

//*****************************************************************************
//
// External declaration for LPC MCU vector table checksum from  Linker Script
//
//*****************************************************************************
WEAK extern void __valid_user_code_checksum();

//*****************************************************************************
#if defined (__cplusplus)
} // extern "C"
#endif
//*****************************************************************************
//
// The vector table.
// This relies on the linker script to place at correct location in memory.
//
//*****************************************************************************
extern void (* const g_pfnVectors[])(void);
__attribute__ ((used,section(".isr_vector")))
void (* const g_pfnVectors[])(void) = {
    // Core Level - CM4
    &_vStackTop,                    // The initial stack pointer
    ResetISR,                       // The reset handler
    NMI_Handler,                    // The NMI handler
    HardFault_Handler,              // The hard fault handler
    MemManage_Handler,              // The MPU fault handler
    BusFault_Handler,               // The bus fault handler
    UsageFault_Handler,             // The usage fault handler
    __valid_user_code_checksum,             // LPC MCU Checksum
    0,                              // Reserved
    0,                              // Reserved
    0,                              // Reserved
    SVC_Handler,                    // SVCall handler
    DebugMon_Handler,               // Debug monitor handler
    0,                              // Reserved
    PendSV_Handler,                 // The PendSV handler
    SysTick_Handler,                // The SysTick handler

    // Chip Level - LPC43 (M4)
    DAC_IRQHandler,           // 16
#if defined (__USE_LPCOPEN)
    M0APP_IRQHandler,         // 17 CortexM4/M0 (LPC43XX ONLY)
#else
    M0CORE_IRQHandler,        // 17
#endif
    DMA_IRQHandler,           // 18
    0,           // 19
    FLASH_EEPROM_IRQHandler,  // 20 ORed flash Bank A, flash Bank B, EEPROM interrupts
    ETH_IRQHandler,           // 21
    SDIO_IRQHandler,          // 22
    LCD_IRQHandler,           // 23
    USB0_IRQHandler,          // 24
    USB1_IRQHandler,          // 25
    SCT_IRQHandler,           // 26
    RIT_IRQHandler,           // 27
    TIMER0_IRQHandler,        // 28
    TIMER1_IRQHandler,        // 29
    TIMER2_IRQHandler,        // 30
    TIMER3_IRQHandler,        // 31
    MCPWM_IRQHandler,         // 32
    ADC0_IRQHandler,          // 33
    I2C0_IRQHandler,          // 34
    I2C1_IRQHandler,          // 35
    SPI_IRQHandler,           // 36
    ADC1_IRQHandler,          // 37
    SSP0_IRQHandler,          // 38
    SSP1_IRQHandler,          // 39
    UART0_IRQHandler,         // 40
    UART1_IRQHandler,         // 41
    UART2_IRQHandler,         // 42
    UART3_IRQHandler,         // 43
    I2S0_IRQHandler,          // 44
    I2S1_IRQHandler,          // 45
    SPIFI_IRQHandler,         // 46
    SGPIO_IRQHandler,         // 47
    GPIO0_IRQHandler,         // 48
    GPIO1_IRQHandler,         // 49
    GPIO2_IRQHandler,         // 50
    GPIO3_IRQHandler,         // 51
    GPIO4_IRQHandler,         // 52
    GPIO5_IRQHandler,         // 53
    GPIO6_IRQHandler,         // 54
    GPIO7_IRQHandler,         // 55
    GINT0_IRQHandler,         // 56
    GINT1_IRQHandler,         // 57
    EVRT_IRQHandler,          // 58
    CAN1_IRQHandler,          // 59
    0,                        // 60
#if defined (__USE_LPCOPEN)
    ADCHS_IRQHandler,         // 61 ADCHS combined interrupt
#else
    VADC_IRQHandler,          // 61
#endif
    ATIMER_IRQHandler,        // 62
    RTC_IRQHandler,           // 63
    0,                        // 64
    WDT_IRQHandler,           // 65
    M0SUB_IRQHandler,         // 66
    CAN0_IRQHandler,          // 67
    QEI_IRQHandler,           // 68
};


//*****************************************************************************
// Functions to carry out the initialization of RW and BSS data sections. These
// are written as separate functions rather than being inlined within the
// ResetISR() function in order to cope with MCUs with multiple banks of
// memory.
//*****************************************************************************
        __attribute__((section(".after_vectors"
)))
void data_init(unsigned int romstart, unsigned int start, unsigned int len) {
    unsigned int *pulDest = (unsigned int*) start;
    unsigned int *pulSrc = (unsigned int*) romstart;
    unsigned int loop;
    for (loop = 0; loop < len; loop = loop + 4)
        *pulDest++ = *pulSrc++;
}

__attribute__ ((section(".after_vectors")))
void bss_init(unsigned int start, unsigned int len) {
    unsigned int *pulDest = (unsigned int*) start;
    unsigned int loop;
    for (loop = 0; loop < len; loop = loop + 4)
        *pulDest++ = 0;
}

//*****************************************************************************
// The following symbols are constructs generated by the linker, indicating
// the location of various points in the "Global Section Table". This table is
// created by the linker via the Code Red managed linker script mechanism. It
// contains the load address, execution address and length of each RW data
// section and the execution and length of each BSS (zero initialized) section.
//*****************************************************************************
extern unsigned int __data_section_table;
extern unsigned int __data_section_table_end;
extern unsigned int __bss_section_table;
extern unsigned int __bss_section_table_end;

//*****************************************************************************
// Reset entry point for your code.
// Sets up a simple runtime environment and initializes the C/C++
// library.
//
//*****************************************************************************
void ResetISR(void) {

// *************************************************************
// The following conditional block of code manually resets as
// much of the peripheral set of the LPC43 as possible. This is
// done because the LPC43 does not provide a means of triggering
// a full system reset under debugger control, which can cause
// problems in certain circumstances when debugging.
//
// You can prevent this code block being included if you require
// (for example when creating a final executable which you will
// not debug) by setting the define 'DONT_RESET_ON_RESTART'.
//
#ifndef DONT_RESET_ON_RESTART

    // Disable interrupts
    __asm volatile ("cpsid i");
    // equivalent to CMSIS '__disable_irq()' function

    unsigned int *RESET_CONTROL = (unsigned int *) 0x40053100;
    // LPC_RGU->RESET_CTRL0 @ 0x40053100
    // LPC_RGU->RESET_CTRL1 @ 0x40053104
    // Note that we do not use the CMSIS register access mechanism,
    // as there is no guarantee that the project has been configured
    // to use CMSIS.

    // Write to LPC_RGU->RESET_CTRL0
    *(RESET_CONTROL + 0) = 0x10DF1000;
    // GPIO_RST|AES_RST|ETHERNET_RST|SDIO_RST|DMA_RST|
    // USB1_RST|USB0_RST|LCD_RST|M0_SUB_RST

    // Write to LPC_RGU->RESET_CTRL1
    *(RESET_CONTROL + 1) = 0x01DFF7FF;
    // M0APP_RST|CAN0_RST|CAN1_RST|I2S_RST|SSP1_RST|SSP0_RST|
    // I2C1_RST|I2C0_RST|UART3_RST|UART1_RST|UART1_RST|UART0_RST|
    // DAC_RST|ADC1_RST|ADC0_RST|QEI_RST|MOTOCONPWM_RST|SCT_RST|
    // RITIMER_RST|TIMER3_RST|TIMER2_RST|TIMER1_RST|TIMER0_RST

    // Clear all pending interrupts in the NVIC
    volatile unsigned int *NVIC_ICPR = (unsigned int *) 0xE000E280;
    unsigned int irqpendloop;
    for (irqpendloop = 0; irqpendloop < 8; irqpendloop++) {
        *(NVIC_ICPR + irqpendloop) = 0xFFFFFFFF;
    }

    // Reenable interrupts
    __asm volatile ("cpsie i");
    // equivalent to CMSIS '__enable_irq()' function

#endif  // ifndef DONT_RESET_ON_RESTART
// *************************************************************

#if defined (__USE_LPCOPEN)
    SystemInit();
#endif

    //
    // Copy the data sections from flash to SRAM.
    //
    unsigned int LoadAddr, ExeAddr, SectionLen;
    unsigned int *SectionTableAddr;

    // Load base address of Global Section Table
    SectionTableAddr = &__data_section_table;

    // Copy the data sections from flash to SRAM.
    while (SectionTableAddr < &__data_section_table_end) {
        LoadAddr = *SectionTableAddr++;
        ExeAddr = *SectionTableAddr++;
        SectionLen = *SectionTableAddr++;
        data_init(LoadAddr, ExeAddr, SectionLen);
    }
    // At this point, SectionTableAddr = &__bss_section_table;
    // Zero fill the bss segment
    while (SectionTableAddr < &__bss_section_table_end) {
        ExeAddr = *SectionTableAddr++;
        SectionLen = *SectionTableAddr++;
        bss_init(ExeAddr, SectionLen);
    }

#if !defined (__USE_LPCOPEN)
// LPCOpen init code deals with FP and VTOR initialisation
#if defined (__VFP_FP__) && !defined (__SOFTFP__)
    /*
     * Code to enable the Cortex-M4 FPU only included
     * if appropriate build options have been selected.
     * Code taken from Section 7.1, Cortex-M4 TRM (DDI0439C)
     */
    // CPACR is located at address 0xE000ED88
    asm("LDR.W R0, =0xE000ED88");
    // Read CPACR
    asm("LDR R1, [R0]");
    // Set bits 20-23 to enable CP10 and CP11 coprocessors
    asm(" ORR R1, R1, #(0xF << 20)");
    // Write back the modified value to the CPACR
    asm("STR R1, [R0]");
#endif // (__VFP_FP__) && !(__SOFTFP__)
    // ******************************
    // Check to see if we are running the code from a non-zero
    // address (eg RAM, external flash), in which case we need
    // to modify the VTOR register to tell the CPU that the
    // vector table is located at a non-0x0 address.

    // Note that we do not use the CMSIS register access mechanism,
    // as there is no guarantee that the project has been configured
    // to use CMSIS.
    unsigned int * pSCB_VTOR = (unsigned int *) 0xE000ED08;
    if ((unsigned int *) g_pfnVectors != (unsigned int *) 0x00000000) {
        // CMSIS : SCB->VTOR = <address of vector table>
        *pSCB_VTOR = (unsigned int) g_pfnVectors;
    }
#endif

#if defined (__USE_CMSIS)
    SystemInit();
#endif

#if defined (__cplusplus)
    //
    // Call C++ library initialisation
    //
    __libc_init_array();
#endif

#if defined (__REDLIB__)
    // Call the Redlib library, which in turn calls main()
    __main();
#else
    main();
#endif

    //
    // main() shouldn't return, but if it does, we'll just enter an infinite loop
    //
    while (1) {
        ;
    }
}

//*****************************************************************************
// Default exception handlers. Override the ones here by defining your own
// handler routines in your application code.
//*****************************************************************************
__attribute__ ((section(".after_vectors")))
void NMI_Handler(void) {
    while (1) {
    }
}
__attribute__ ((section(".after_vectors")))
void HardFault_Handler(void) {
    while (1) {
    }
}
__attribute__ ((section(".after_vectors")))
void MemManage_Handler(void) {
    while (1) {
    }
}
__attribute__ ((section(".after_vectors")))
void BusFault_Handler(void) {
    while (1) {
    }
}
__attribute__ ((section(".after_vectors")))
void UsageFault_Handler(void) {
    while (1) {
    }
}
__attribute__ ((section(".after_vectors")))
void SVC_Handler(void) {
    while (1) {
    }
}
__attribute__ ((section(".after_vectors")))
void DebugMon_Handler(void) {
    while (1) {
    }
}
__attribute__ ((section(".after_vectors")))
void PendSV_Handler(void) {
    while (1) {
    }
}
__attribute__ ((section(".after_vectors")))
void SysTick_Handler(void) {
    while (1) {
    }
}

//*****************************************************************************
//
// Processor ends up here if an unexpected interrupt occurs or a specific
// handler is not present in the application code.
//
//*****************************************************************************
__attribute__ ((section(".after_vectors")))
void IntDefaultHandler(void) {
    while (1) {
    }
}

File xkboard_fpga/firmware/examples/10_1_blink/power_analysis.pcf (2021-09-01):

[[Info]]
_PARENT: none
_FILE_FORMAT: 1.00
_DATA_VALUES: 1.00
_STATUS: Advanced
_FAMILY: se5c00

[[Project]]
DesignName: tutorial_led_blink
Version: 8.0
Family: MachXO3D
Device: LCMXO3D-9400HC
Package: QFN72
Operating: Commercial
Performance: -6
PartName: LCMXO3D-9400HC-6SG72C

[[Settings]]
EstimationMode: Medium
ProcessType: Typical
SoftwareMode: Calculation
SectionY: Total Power
SectionX: Vccio 3.3
SectionLowerLimit: 3.0000
SectionUpperLimit: 3.6000
SectionResolution: 0.1200
TempAmbY: Ambient Temperature
TempAmbX: Ambient Temperature
TempAmbLowerLimit: -40.0000
TempAmbUpperLimit: 125.0000
TempAmbResolution: 33.0000
FreqY: Total Power
FreqX: COMBINATORIAL
FreqLowerLimit: 0.0000
FreqUpperLimit: 100.0000
FreqAmbResolution: 20.0000
PowerMode: Normal
DisableBandgap: false
DisablePor: false
DisableDll: false
DisableOsc: false
DisablePLL0: false
DisablePLL1: false
DisableInRd0: false
DisableInRd1: false
DisableInRd2: false
DisableInRd3: false
DisableInRd4: false
DisableInRd5: false
DisableInRd6: false
DisableInRd7: false
EnablePg0: false
EnablePg1: false
EnablePg2: false
EnablePg3: false
EnablePg4: false
EnablePg5: false
EnablePg6: false
EnablePg7: false
DisableLVDS: false
DisableLVDS1: false
DisableLVDS2: false
DisableLVDS3: false
DisableLVDS4: false
DisableLVDS5: false
DisableLVDS6: false
DisableLVDS7: false
DisableSlewrate0: false
DisableSlewrate1: false
DisableSlewrate2: false
DisableSlewrate3: false
DisableSlewrate4: false
DisableSlewrate5: false

[[Thermal]]
Airflow: 200 LFM
AmbientTemperature: 25
CustomThetaSA: -1
JunctionTemperature: 25.89
MaxSafeAmbient: 83.08
ThetaBA: 10.0
ThetaCS: 0
ThetaEffective: 7.91
ThetaJA: 20.59
ThetaJB: 12.88
ThetaJC: 0
ThetaSA: -1
UserThetaBA: No
UserThetaCS: No
UserThetaEffective: No
UserThetaJA: No
UserThetaJB: No
UserThetaJC: No
UserThetaSA: No
thetaBoard: Medium Board
thetaHeatSink: No Heat Sink
thetaOption: ThermalModels

[[VDPM]]
Supply = Voltage, DPM
Vccio 3.3 = 3.300, 1.00
Vccio 2.5 = 2.500, 1.00
Vccio 1.8 = 1.800, 1.00
Vccio 1.5 = 1.500, 1.00
Vccio 1.2 = 1.200, 1.00
Vcc = 3.300, 1.00

[[Logic]]
Clk = F, AF, LUT, RAM, RIPPLE, REG, X0, X1, X2, X6, ISB, ISBLUT, ISBCE, ISBLSR, ISBM, ISBCLK
COMBINATORIAL = 0.0000^d^, 10.0000^d^, 109, 0, 11, 0, 73, 50, 181, 70, 181, 2, 54, 122, 3, 2
jtaghub16_jtck = 0.0000^d^, 10.0000^d^, 196, 0, 26, 209, 372, 167, 688, 117, 860, 588, 71, 122, 70, 125
i_clock_N = 0.0000^d^, 10.0000^d^, 165, 0, 57, 241, 295, 178, 562, 102, 1935, 1464, 52, 262, 139, 148

[[Clocks]]
Clk = F, Duty, Pfeed, Ptrunk, Pspine, Ptap, Pbranch, Strunk, Sspine, Stap, Sbranch, Etb, Ebg, Elr
COMBINATORIAL = 0.0000^d^, 100, 0, 0, 0, 0, 0, t15_1, c13_3, r11_2_r18_2_r26_2, b_50, 0, 0, 0
jtaghub16_jtck = 0.0000^d^, 100, f25_2, t15_1, s13_2_s36_1, p19_2_p23_3_p27_2, c20_7_c24_13_c28_4, t16_2, c13_1_c14_3, r11_1_r18_4_r26_1, b_36, 0, 0, 0
i_clock_N = 0.0000^d^, 100, 0, t15_1, s14_1_s38_1, p18_2_p22_2_p26_2_p30_2, c19_3_c23_10_c27_10_c31_2, t15_3_t16_2, c13_3_c36_3_c37_2, r18_5_r26_7, b_58, 0, 0, 0

[[Input Output]]
Clk = _Type, _Mode, F, AF, IP, OP, PG, Cload, Bank, _ActualMode, _Pull, X0, X1, X2, X6, ISB
COMBINATORIAL = LVCMOS33, none, 0.0000^d^, 10.0000^d^, 1, 0, OFF, 5, 2, none, UP, 0, 0, 0, 0, 0
COMBINATORIAL = LVCMOS33, none, 0.0000^d^, 10.0000^d^, 2, 0, OFF, 5, 2, none, DOWN, 0, 0, 0, 0, 0
i_clock_N = LVCMOS33-8mA-SLEW:FAST, none, 0.0000^d^, 10.0000^d^, 0, 3, N/A, 5, 2, none, DOWN, 0, 0, 0, 0, 0
i_clock_N = LVCMOS33, none, 0.0000^d^, 10.0000^d^, 1, 0, OFF, 5, 0, none, DOWN, 0, 0, 0, 0, 0

[[Bidi]]
ClkInpName = _Type, _Mode, InpF, InpAF, Bidi, PG, ClkOutName, OutF, OutAF, Duty, Cload, Bank, _ActualMode, _Pull, X0, X1, X2, X6, ISB
COMBINATORIAL = LVCMOS33-8mA-SLEW:SLOW, none, 0.0000^d^, 10.0000^d^, 2, OFF, N/A, 0.0000^d^, 10.0000^d^, 50, 5, 2, none, NONE, 0, 0, 0, 0, 0
COMBINATORIAL = LVCMOS33-8mA-SLEW:SLOW, none, 0.0000^d^, 10.0000^d^, 1, OFF, N/A, 0.0000^d^, 10.0000^d^, 50, 5, 2, none, UP, 0, 0, 0, 0, 0

[[Bank Voltage]]
Bank = Voltage, InRD, LVDSO, PG, SLEWRATE
0 = Vccio 3.3, No, No, OFF, No
1 = Vccio 2.5, No, N/A, N/A, No
2 = Vccio 3.3, No, N/A, OFF, No
3 = Vccio 2.5, No, N/A, N/A, No

[[Termination]]
_Type = IP, OP, Bidi, Duty, Bank, Rth, Vth
LVCMOS33 = 3, 0, 0, 0.000000, 2, 1.0E12, 0
LVCMOS33-8mA-SLEW:FAST = 0, 3, 0, 0.000000, 2, 1.0E12, 0
LVCMOS33 = 1, 0, 0, 0.000000, 0, 1.0E12, 0
LVCMOS33-8mA-SLEW:SLOW = 0, 0, 3, 50.000000, 2, 1.0E12, 0

[[SP RAM]]
Clk = EBR, F, AF, _Type, X0, X1, X2, X6, ISB

[[DP RAM]]
RdClk = RdF, RdAF, EBR, WrClk, WrF, WrAF, _TypeA, _TypeB, X0, X1, X2, X6, ISB

[[DP RAM True]]
ClkA = aF, aAF, EBR, ClkB, bF, bAF, _TypeA, _TypeB, X0, X1, X2, X6, ISB
i_clock_N = 0.0000^d^, 10.0000^d^, 1, i_clock_N, 0.0000^d^, 10.0000^d^, DP8KC_NORM_PORTA, DP8KC_NORM_PORTB, 0, 0, 0, 0, 0
i_clock_N = 0.0000^d^, 10.0000^d^, 1, jtaghub16_jtck, 0.0000^d^, 10.0000^d^, DP8KC_NORM_PORTA, DP8KC_NORM_PORTB, 0, 0, 0, 0, 0

[[FIFO DC]]
RdClk = RdF, RdAF, EBR, WrClk, WrF, WrAF, _TypeA, _TypeB, X0, X1, X2, X6, ISB

[[PLL]]
OutClk = inF, N, V, M, PLL, STANDBY
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
